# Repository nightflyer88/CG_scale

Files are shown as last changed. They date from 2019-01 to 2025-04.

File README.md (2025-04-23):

# CG scale

The CG Scale firmware is open source and available for free. If you like it, support the project with a donation and help it continue to develop.

Donate (https://www.paypal.com/cgi-bin/webscr?cmd=_s-xclick&hosted_button_id=R69PMKTCXQBUU&source=url)

Arduino-based balance scale for weighing model aircraft. Relatively few components are required and should be easy to recreate even for electronics beginners.
The most important functions:

- supports scales with 2 or 3 load cells
- supports ESP8266 (also Wifi Kit 8) and Arduino with ATmega328, ATmega32u4
- Automatic calibration based on a reference object, meaning no laborious determination of the calibration values
- Display via OLED display
- Battery voltage can be measured
- Settings are made through a menu via the serial interface
- With the ESP8266, the settings can also be easily made via the webpage
- Parameters are permanently saved in the EEprom and do not have to be re-parameterized after a software update
- Only a few components required, making it quick and easy to assemble

# ENGLISH

Here is the assembly and user guide for this scale model balance
You can find the full description [HERE](https://github.com/ZINKTiti/CG_scale-1/wiki/ENGLISH)

# FRANCAIS

Voici le guide de montage et d'utilisation de cette balance pour model réduit
Vous trouver toute la description [ICI](https://github.com/ZINKTiti/CG_scale-1/wiki/FRANCAIS)

# DEUTSCH

Hier finden Sie die Montage- und Bedienungsanleitung für diese Modellwaage
Sie finden die gesamte Beschreibung [HIER](https://github.com/nightflyer88/CG_scale/wiki)

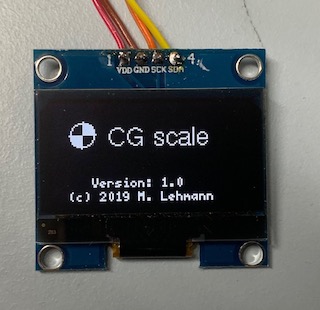
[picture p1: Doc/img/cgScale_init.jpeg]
init

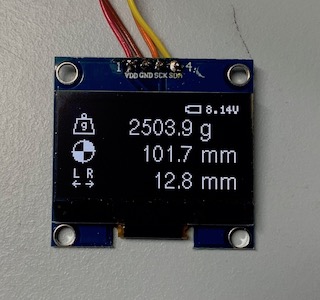
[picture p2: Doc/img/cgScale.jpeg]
run

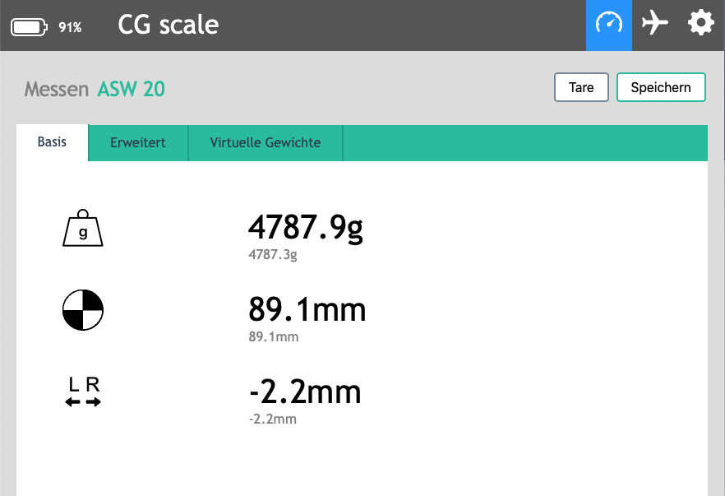
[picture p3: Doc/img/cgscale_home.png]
cgscale_home

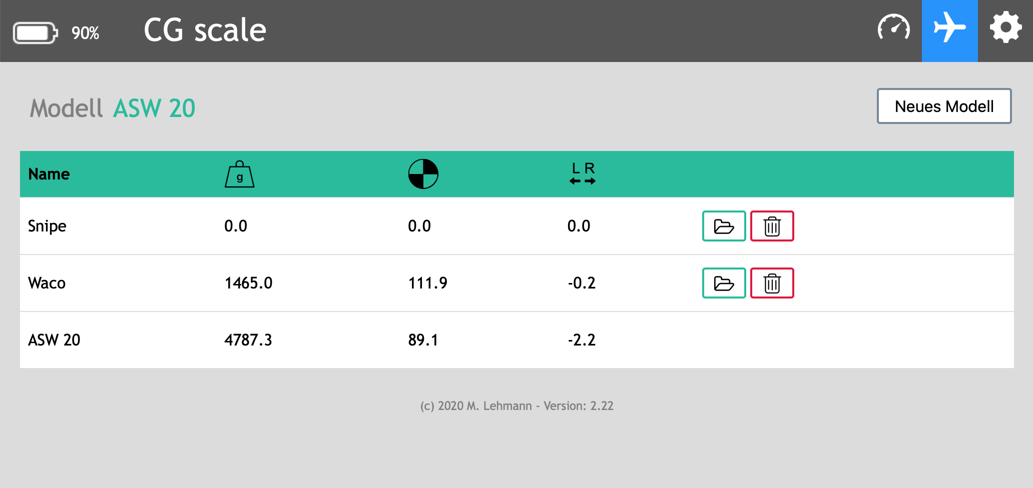
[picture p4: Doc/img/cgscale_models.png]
cgscale_models

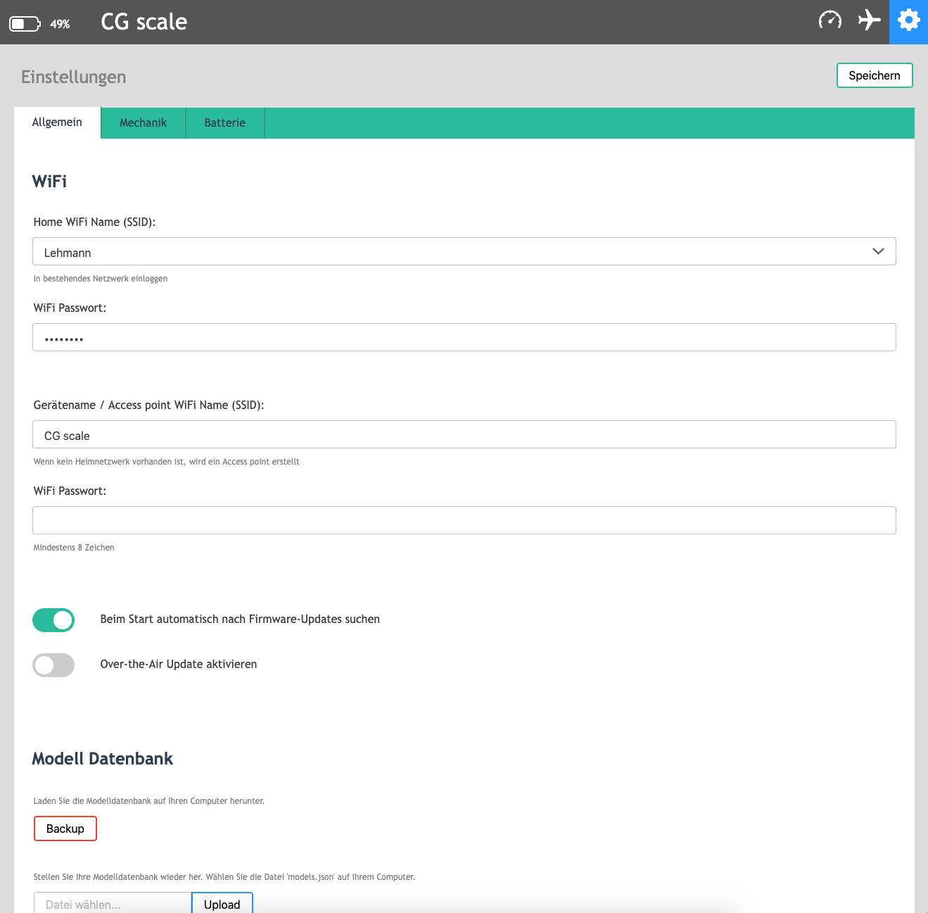
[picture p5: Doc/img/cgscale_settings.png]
cgscale_settings

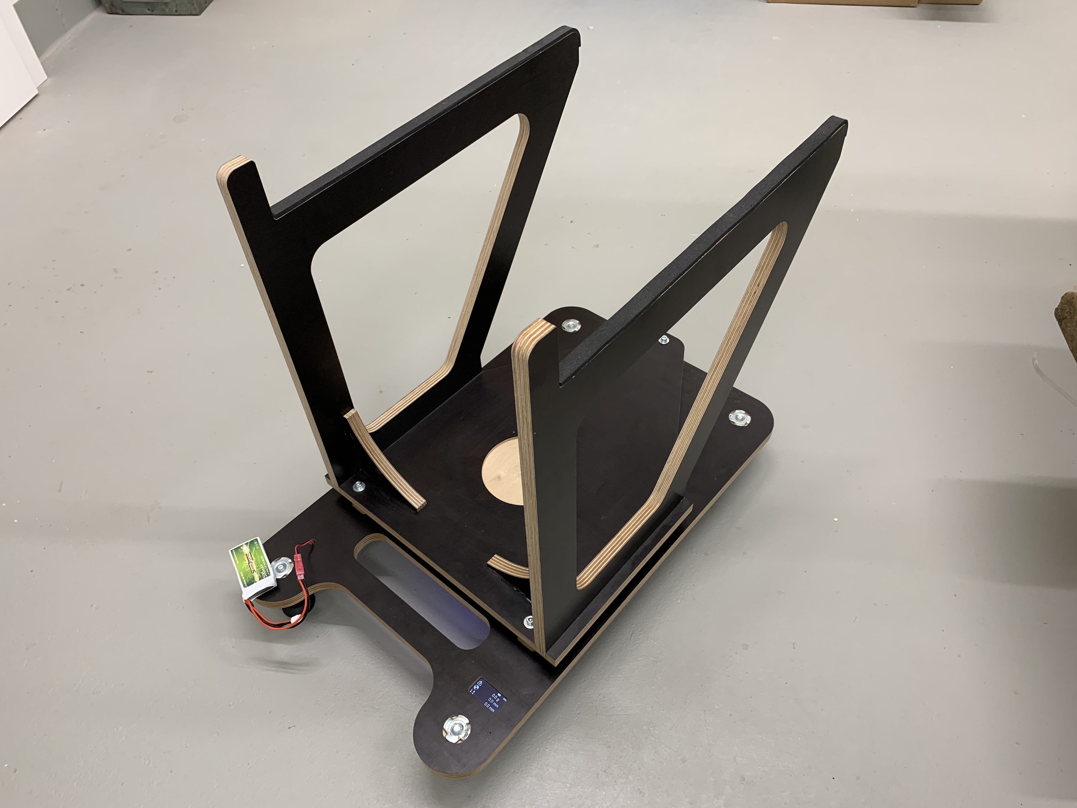
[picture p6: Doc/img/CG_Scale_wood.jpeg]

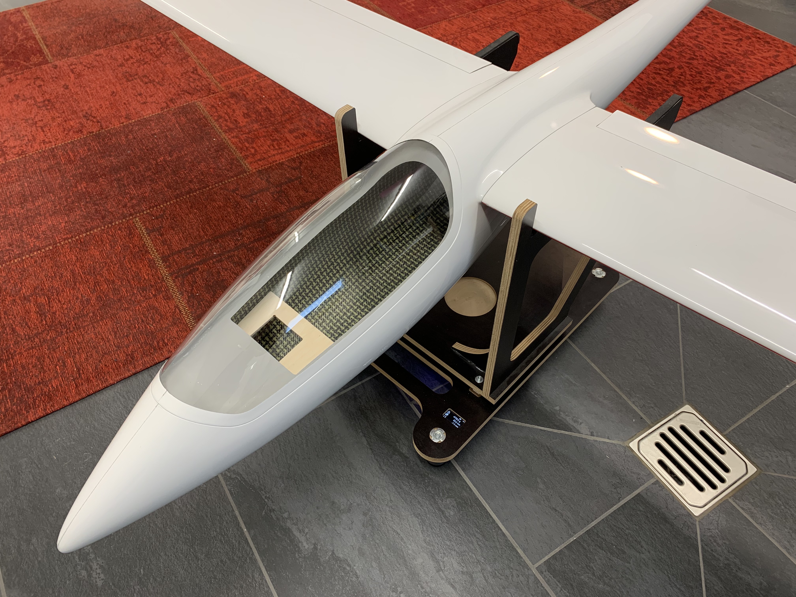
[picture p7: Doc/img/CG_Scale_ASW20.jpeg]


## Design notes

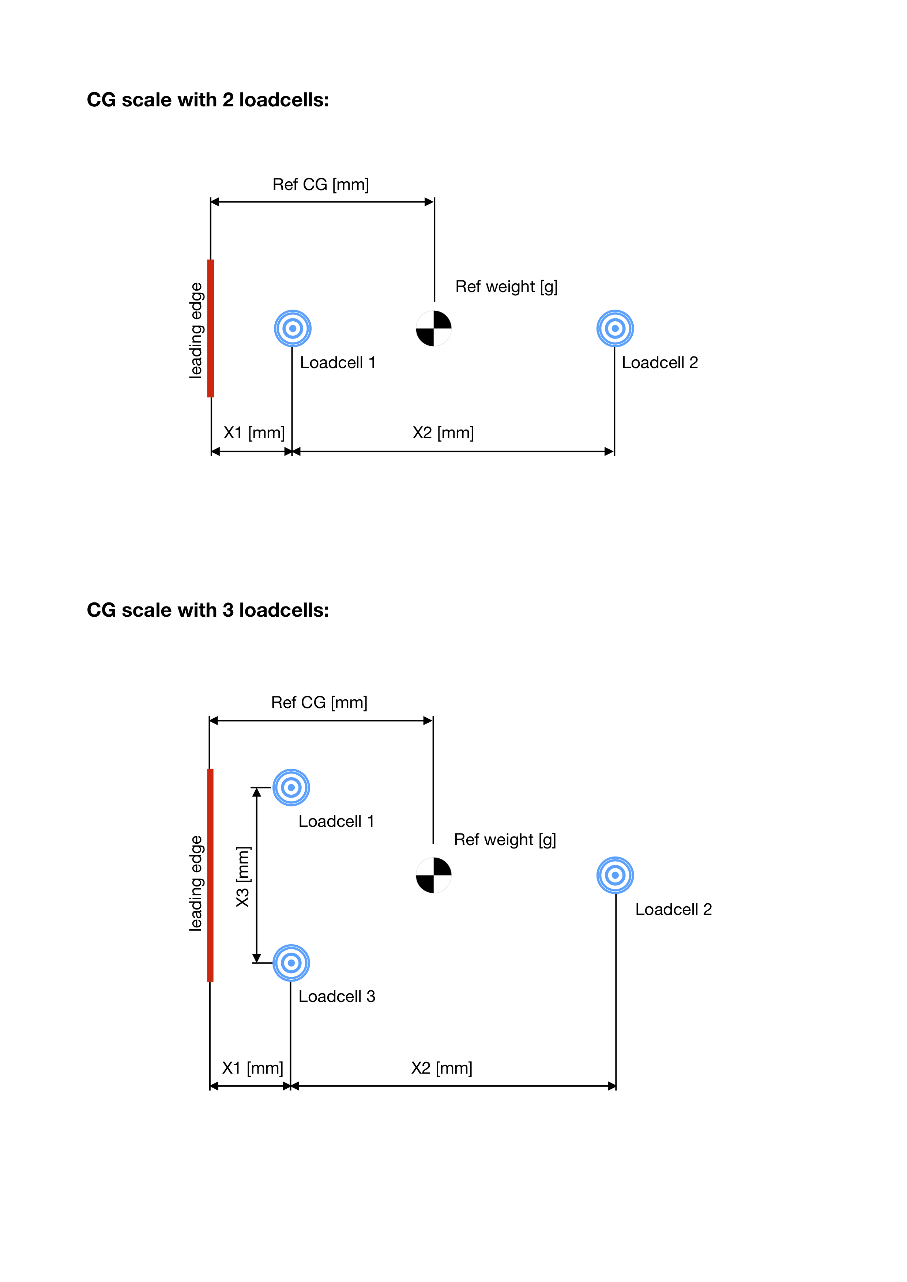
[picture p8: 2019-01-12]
Doc/CG_scale_mechanics.png

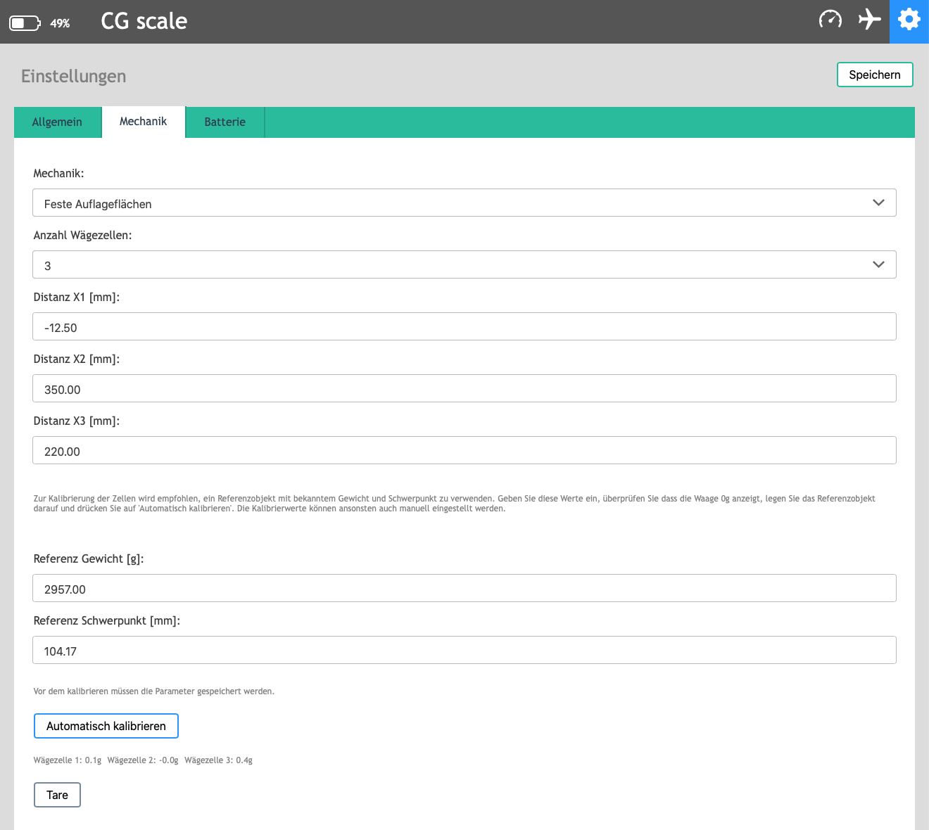
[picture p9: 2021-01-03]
Doc/img_DE/cgscale_settings_mechanic.png

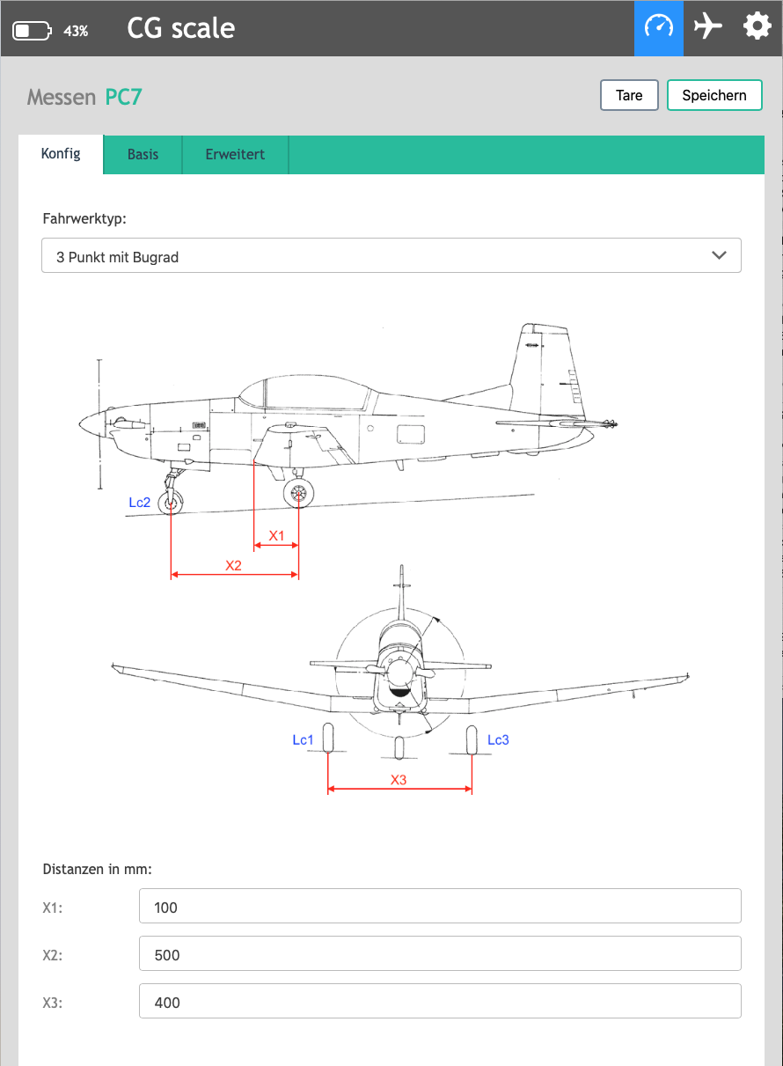
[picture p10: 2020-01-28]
Doc/img_DE/cgscale_V2_homeconfig3.png

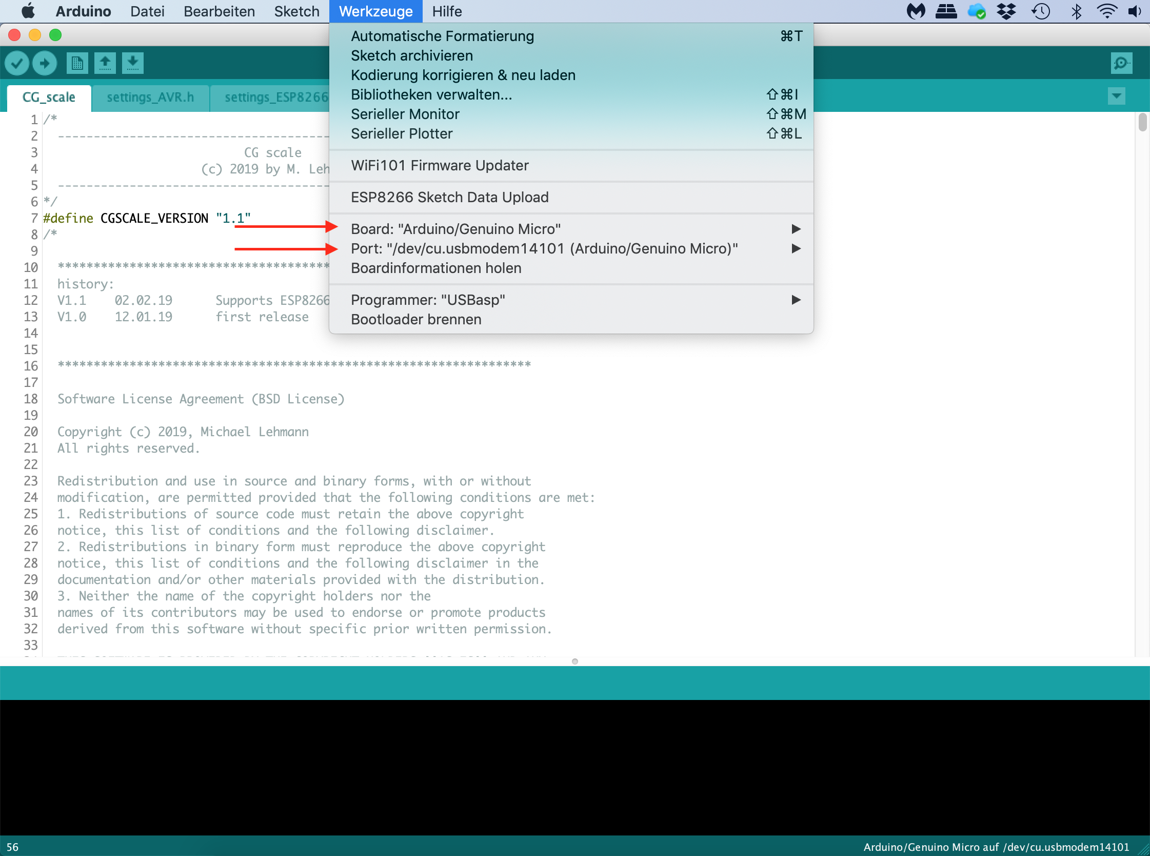
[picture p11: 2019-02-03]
Doc/img_DE/arduino_board.png

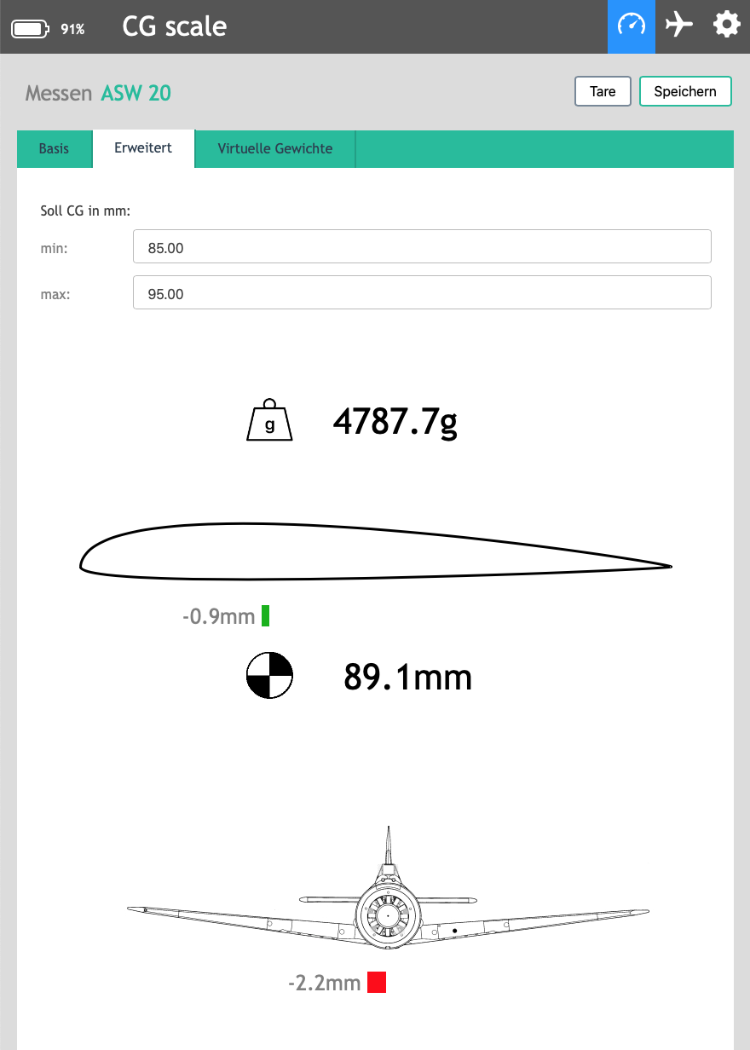
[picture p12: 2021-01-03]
Doc/img_DE/cgscale_home_extended.png

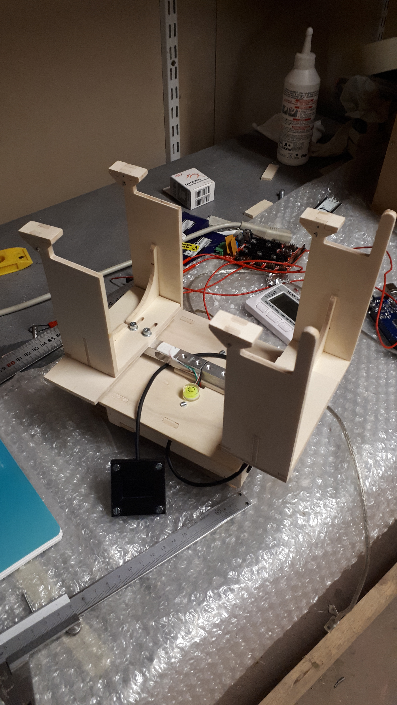
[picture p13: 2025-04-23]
Doc/Oled BOX/img/Balance.jpg

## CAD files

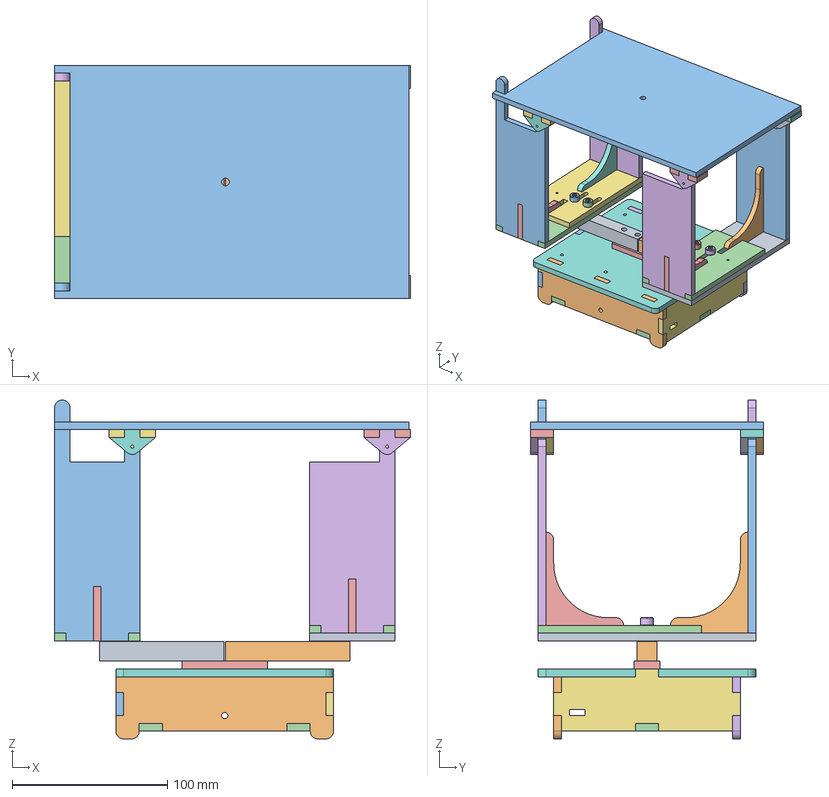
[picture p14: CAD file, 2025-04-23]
Doc/Balance CPT 5mm/Freecad/Balance 5mm.FCStd
229.0 x 150.0 x 218.0 mm
Dessus ESP8266
Coté droit
Avant
Dessous
Calle
CoterGauche
Arriere
Dessus ArduinoNano
Load Cell
M5x20-Screw
M5x20-Screw004
M5x20-Screw005
M5x20-Screw006
M5x20-Screw007
M5x20-Screw008
M5x20-Screw009
M5x20-Screw010
SupportLateralAvantGauche
PlateauBasGauche
RaidisseurGauche
SupportLateralAvantDroit
PlateauBasDroit
RaidisseurDroit
PlateauBasArriereDroit
RaidisseurGaucheDroit
SupportLateralArriereDroit
PlateauBasDroitArriere
RaidisseurDroitArriere
SupportLateralArriereGauche
SupportReposeAile
SupportLateral
SupportLateral001

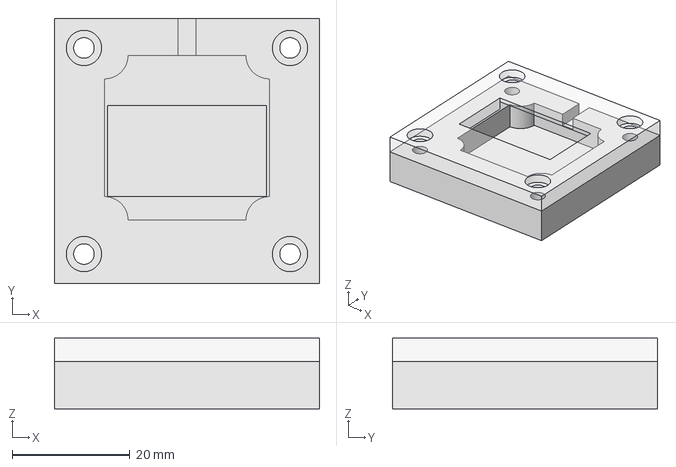
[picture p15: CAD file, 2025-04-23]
Doc/Oled BOX/FreeCad Files/Box_Oled.FCStd
45.0 x 45.0 x 12.0 mm
Couvercle001
Bas001

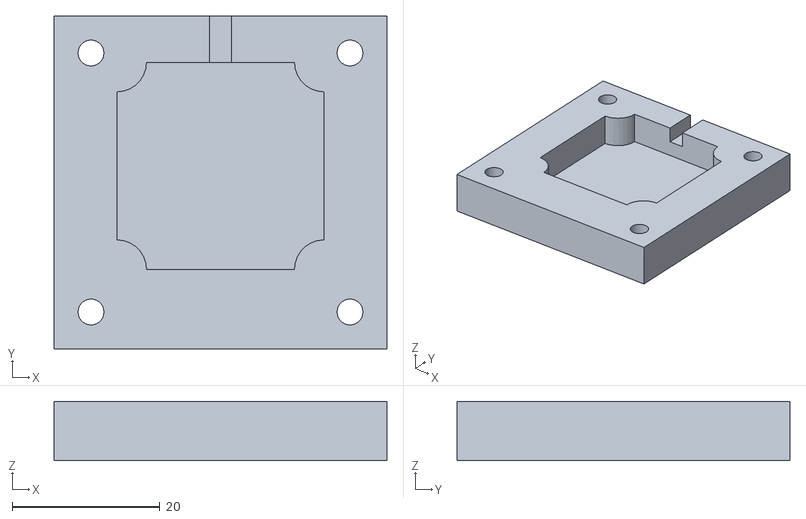
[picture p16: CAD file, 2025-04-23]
Doc/Oled BOX/Stl/Box_Oled_Bottom.stl
45.0 x 45.0 x 8.00

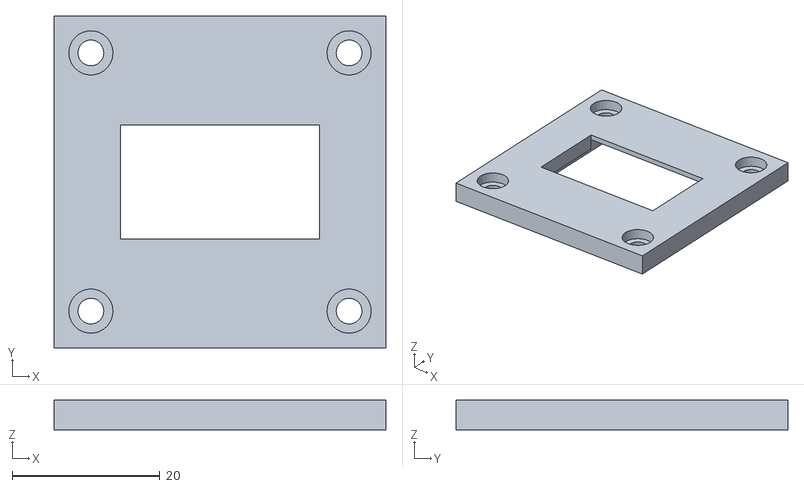
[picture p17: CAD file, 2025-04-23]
Doc/Oled BOX/Stl/Box_Oled_Top.stl
45.0 x 45.0 x 4.00

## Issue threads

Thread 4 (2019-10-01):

NodeMCU mit CG Scale Verbindungsprobleme mit lokalem Wifi

kkberg, 2019-10-01:
Leider verbindet sich das System nicht mit dem lokalen WiFi, obwohl SSID und Wlan-Schlüssel korrekt sind. Parameter werden gespeichert und das wird auch bestätigt.
Nach dem Speichern bleibt  CG Scale als SSID, also im AP-Modus, was auch nach Neustart so bleibt.

kkberg, 2019-10-01:
Es sieht m.E. so aus, dass nicht lange genug nach vorhandenen WiFi's gesucht wird und dadurch direkt in den AP-Modus gewechselt wird.

kkberg, 2019-10-01:
Ich denke das es diese Stelle ist, die ich verändern muss.
#define TIMEOUT_CONNECT 25000   //ms

nightflyer88, 2019-10-07:
Was hast du denn für einen Router ? Es ist möglich das einige etwas mehr Zeit benötigen. Mit 25000ms funktioniert es ?

kkberg, 2019-10-07:
Ich habe eine Fritzbox 7590. Den Wert habe ich angepasst auf 50000ms und das funktioniert. Ich habe inzwischwn auch eine RS232 to Wifi Bridge gefunden, was für mich noch angenehmer ist. Ost es angedacht so etwas auch noch zu implementieren? Übrigens eine tolle Arbeit die Du gemacht hast. TOP

nightflyer88, 2019-10-07:
Bis jetzt ist sowas nicht angedacht. Für was brauchst du die Bridge, oder wie funktioniert das genau ?

kkberg, 2019-10-07:
Ich brauche nur eine Com-Port, ohne eine Oberfläche.

kkberg, 2019-10-07:
Entschuldige bitte, ich habe das jetzt falsch gepostet. Das sollte hier nicht rein. Ich habe noch ein Projekt mit ESP und mir ist was durcheinander geraten.

Closed 2019-10-07.

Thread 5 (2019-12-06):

Drehmoment des Flügelpaares beim messen des Rumpfes addieren

Rolf-G, 2019-12-06:
Erst mal vielen Dank für das hervoragende und sehr praxistaugliche Programm. Die Möglichkeit, mehrere Modelle (mit jeweils eigenen Abständen der Wägepunkte/Referenzpunkt) ist genial. Leider reichen meine Programmier Kenntnisse nicht aus, um selbst folgende Erweiterung einzupflegen, daher schlage ich das einfach mal hier vor:

Könnte zur tatsächlichen Messung bedarfsweise ein weiteres "virtuelles" Drehmoment (Gewicht/Abstand) mit gerechnet werden ?

Nimmt man die abmontierten Flügel und bestimmt deren Schwerpunkt/Gewicht einmal alleine, und nimmt diese Werte dann als "virtuelles" Gewicht, könnte man beim Bauen am Rumpf in der Werkstatt (wo man im allgemeinen ja besonderes bei drößeren Fliegern die Flügel eben nicht montiert hat) allein durch Auswiegen des Rumpfes ablesen, wo später bei montiertem Flächeln der Schwerpunkt sein wird. Man bräuchte zum Überprüfen also nicht jedesmal die Flügel montieren.

Hoffe, ich habe mich halbwegs verständlich ausgedrückt.
MfG Rolf

nightflyer88, 2020-11-01:
Eingebaut bei V2.2

Rolf-G, 2020-11-02:
Suuuuuuuuuuper, tausend Dank

Closed 2020-11-01.

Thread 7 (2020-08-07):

Fehler der Version 2.0 beim Kompilieren.

Skippydi, 2020-08-07:
Beim Kompilieren der V2.0 erscheint folgender Fehler:

Sketch wird kompiliert...

CG_scale:103:13: error: 'MAX_MODELNAME_LENGHT' was not declared in this scope

   char name[MAX_MODELNAME_LENGHT + 1] = "";

             ^~~~~~~~~~~~~~~~~~~~

Bibliothek HX711_ADC in Version 1.2.1 im Ordner: C:\Users\Skippy\Documents\Arduino\libraries\HX711_ADC  wird verwendet

Bibliothek U8g2 in Version 2.27.6 im Ordner: C:\Users\Skippy\Documents\Arduino\libraries\U8g2  wird verwendet

Bibliothek EEPROM in Version 2.0 im Ordner: C:\Program Files (x86)\Arduino\hardware\arduino\avr\libraries\EEPROM  wird verwendet

Bibliothek Wire in Version 1.0 im Ordner: C:\Program Files (x86)\Arduino\hardware\arduino\avr\libraries\Wire  wird verwendet

Bibliothek SPI in Version 1.0 im Ordner: C:\Program Files (x86)\Arduino\hardware\arduino\avr\libraries\SPI  wird verwendet

exit status 1

'MAX_MODELNAME_LENGHT' was not declared in this scope

Mein Fehler oder, fehlt das was??

Gruß Dietmar

Skippydi, 2020-08-08:
Hat sich erledigt

fheinze26, 2020-09-24:
Hi @Skippydi und @nightflyer88
ich versuche gerade die Version 2.0 auf einen Arduino UNO zu installiere und bekomme eine ganz ähnlich Fehlermeldung. Wie habt ihr das Problem gelöst? VIELEN DANK

Arduino: 1.8.12 (Mac OS X), Board: "Arduino Uno"

In file included from /Users/fheinze/Downloads/CG_scale/CG_scale.ino:83:0:
settings_AVR.h:54:39: error: 'A9' was not declared in this scope
 #define PIN_LOADCELL3_DOUT            A9
                                       ^
/Users/fheinze/Downloads/CG_scale/CG_scale.ino:89:136: note: in expansion of macro 'PIN_LOADCELL3_DOUT'
 HX711_ADC LoadCell[]{HX711_ADC(PIN_LOADCELL1_DOUT, PIN_LOADCELL1_PD_SCK),HX711_ADC(PIN_LOADCELL2_DOUT, PIN_LOADCELL2_PD_SCK),HX711_ADC(PIN_LOADCELL3_DOUT, PIN_LOADCELL3_PD_SCK)};
                                                                                                                                        ^~~~~~~~~~~~~~~~~~
sketch/settings_AVR.h:54:39: note: suggested alternative: 'A7'
 #define PIN_LOADCELL3_DOUT            A9
                                       ^
/Users/fheinze/Downloads/CG_scale/CG_scale.ino:89:136: note: in expansion of macro 'PIN_LOADCELL3_DOUT'
 HX711_ADC LoadCell[]{HX711_ADC(PIN_LOADCELL1_DOUT, PIN_LOADCELL1_PD_SCK),HX711_ADC(PIN_LOADCELL2_DOUT, PIN_LOADCELL2_PD_SCK),HX711_ADC(PIN_LOADCELL3_DOUT, PIN_LOADCELL3_PD_SCK)};
                                                                                                                                        ^~~~~~~~~~~~~~~~~~
settings_AVR.h:55:39: error: 'A10' was not declared in this scope
 #define PIN_LOADCELL3_PD_SCK          A10
                                       ^
/Users/fheinze/Downloads/CG_scale/CG_scale.ino:89:156: note: in expansion of macro 'PIN_LOADCELL3_PD_SCK'
 HX711_ADC LoadCell[]{HX711_ADC(PIN_LOADCELL1_DOUT, PIN_LOADCELL1_PD_SCK),HX711_ADC(PIN_LOADCELL2_DOUT, PIN_LOADCELL2_PD_SCK),HX711_ADC(PIN_LOADCELL3_DOUT, PIN_LOADCELL3_PD_SCK)};
                                                                                                                                                            ^~~~~~~~~~~~~~~~~~~~
sketch/settings_AVR.h:55:39: note: suggested alternative: 'A1'
 #define PIN_LOADCELL3_PD_SCK          A10
                                       ^
/Users/fheinze/Downloads/CG_scale/CG_scale.ino:89:156: note: in expansion of macro 'PIN_LOADCELL3_PD_SCK'
 HX711_ADC LoadCell[]{HX711_ADC(PIN_LOADCELL1_DOUT, PIN_LOADCELL1_PD_SCK),HX711_ADC(PIN_LOADCELL2_DOUT, PIN_LOADCELL2_PD_SCK),HX711_ADC(PIN_LOADCELL3_DOUT, PIN_LOADCELL3_PD_SCK)};
                                                                                                                                                            ^~~~~~~~~~~~~~~~~~~~
CG_scale:103:13: error: 'MAX_MODELNAME_LENGHT' was not declared in this scope
   char name[MAX_MODELNAME_LENGHT + 1] = "";
             ^~~~~~~~~~~~~~~~~~~~
exit status 1
'A9' was not declared in this scope

Dieser Bericht wäre detaillierter, wenn die Option
"Ausführliche Ausgabe während der Kompilierung"
in Datei -> Voreinstellungen aktiviert wäre.

Skippydi, 2020-09-24:
Das Problem ist, das die Firmware für einen ESP8266 geschrieben wurde. Mit einem ESP hatte ich den Fehler nicht mehr. Außerdem ist der auch erheblich komfortabler mit WLAN.

fheinze26, 2020-09-24:
Danke für die schnelle Antwort @Skippydi
Ich habe jetzt alle Versionen bis 1.0 durchprobiert und immer erhalten ich denselben Fehler "A9' was not declared in this scope" - Es scheint im allgemeinen nicht mit dem ATmega328 zu funktionieren oder ich mach was falsch. Dann probiere ich mal einen ESP8266. Ist nur schade weil ich noch ein paar Arduino UNOs zuhause rumliegen habe. Danke nochmal

Skippydi, 2020-09-24:
Der UNO hat keinen A9 Input/Output das ist das Problem

Von meinem iPhone gesendet

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

fheinze26, 2020-09-24:
Stimmt, der hat ja nur Analog A0-A5 jetzt wo Du´s sagst, macht total Sinn ;)

Closed 2020-08-08.

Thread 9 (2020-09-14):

Tara Button auf Kalibrierungs-Seite

Blackforrestpilot, 2020-09-14:
Verbesserungsvorschlag:
Einen Tara Button auf der Kalibrierungs Seite einfügen.
Das Kalibrieren wird dann vereinfacht und weniger fehlerfällig.
Ich würde das gerne selber programmieren,finde aber die Sourcen der Web GUI nicht.

Gruss
Christoph

nightflyer88, 2020-09-27:
Habe ich nun eingebaut, ist aber noch nicht getestet: d1ad6b6c4293ef6ffc48abfb7cc4e12905cb4f5f

Closed 2020-09-27.

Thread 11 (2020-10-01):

Seltsame Gewichtsanzeige bzw. falsches Gewicht ESP8266

Skippydi, 2020-10-01:
Erstmal vielen Dank für die Software. Ich habe sie auf einem EP8266 installiert mit 2 Wägezellen (Rot von Aliexpress 5kg). Soweit funktioniert auch alles, aber das angezeigt Gewicht stimmt hinten und vorne nicht. Beim Kalibrieren habe ich ein Gewicht von 1711g SP 112.5mm eingesetzt, angezeigt wird nach dem kalibrieren 1712.9 und SP 113.4. Damit könnte ich leben. Aber beim normalen wiegen zeigt die Waage zwischen 1917g und 1735g an. Bei verschieden Wiegevorgängne habe ich niemals ein gleiches Gewicht, schon gar nicht das Kalibriergewicht. Woran könnte das liegen?
Danke für eine Antwort.

nightflyer88, 2020-10-03:
Evtl. falsch verdrahtet oder Wiegezelle/HX711 defekt. Ist die Betriebsspannung der HX711 auf 3.3v stabilisiert ?

Skippydi, 2020-10-03:
Die HX711 sind richtig verdrahtet,(mit separater Software getestet und auch nachkontrolliert),
 die 3.3 Volt liefert der ESP8266, sollte also auch ok sein. Seltsam ist nur das beim Kalibrieren das richtige Gewicht +/- 2 Gramm richtig berechnet wird.
Wenn ich jedoch meinen Segler wiege, der 460g wiegt, wird 682g angezeigt. Aber der berechnete SP stimmt fast zu 100% ( 54.2mm statt 55mm)
Ich bin echt ratlos.

nightflyer88, 2020-10-04:
In den Einstellungen siehst du die Einzelgewichte der Zellen, belaste jede Zelle separat mit einem Gewicht, und prüfe was dabei angezeigt wird. Es könnte sein, dass eine Zelle defekt ist. Hast du die Abstände richtig eingegeben ? Was für Kalibrierwerte hast du ?

Skippydi, 2020-10-04:
Hallo Nightflyer88, es tatsächlich eine Alumesszelle defekt. Habe ich ausgetauscht und jetzt sind die Messwerte und die Kalibrierung TOP!! Ganz herzlichen Dank für deine HIlfe. Die Messzelle funktionierte zwar, aber stellte sich nicht immer korrekt auf Null.

Closed 2020-10-04.

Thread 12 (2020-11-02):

V2.2 Zu wenig Speicherplatz

chaoscrack, 2020-11-02:
Das hochladen der neuen Firmware ging gut. Jedoch beim upload des Filesystems erhielt ich die Fehlermeldung dass nicht genügend Speicherplatz vorhanden sei.
Um auszuschliessen dass der Speicher beim Update gelöscht wurde hab ich nochmals alles via pyFlascher hochgeladen und vorher den Speicher löschen lassen. Leider blieb das Problem das selbe.
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

Rolf-G, 2020-11-04:
Hallo Patrick, ich hatte nach dem Laden der Firmware mit dem NodeMCU pyFlasher erst das Problem, das die update Seite nicht gefunden wurde (vermute, weil eine 1.x Version vorher drauf war) und die Webseiten noch die alten waren. Habe mir dann geholfen, indem ich das Filesystem einfach mit dem ESP8266 Sketch upload Tool im Arduino INO Programm hochgeladen habe.

chaoscrack, 2020-11-05:
@Rolf-G
Wie geschrieben hab ich mit dem flashen zuerst alles löschen lassen. Ohne Erfolg.
Update-Seite kann ich aufrufen. Nur anschliessend krieg ich die erwähnte Fehlermeldung.

Mittels Arduino IDE kann ich das Filesystem hochladen, doch ich verliere ich anschliessend immer wieder die Verbindung zum AccessPoint und kann somit auch nicht die Haupt- oder Setupseite aufrufen.

Wenn ich versuche den ESP via Arduino IDE zu flashen erhalte ich schon beim Kompilieren Fehlermeldungen. Diese lautet ` 'class HTTPClient' has no member named 'setRedirectLimit'` und die IDE steht bei der Zeile 1128 https.setRedirectLimit(0);

chaoscrack, 2020-11-08:
Ich habs auch mit einem Wemos D1 mini V3.1.0 probiert. Die Fehlermeldungen sind die selben.
@nightflyer88 mach ich was falsch, oder wo könnte der Fehler liegen?

nightflyer88, 2020-11-27:
ist mit V2.21 behoben

Closed 2020-11-27.

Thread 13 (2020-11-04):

virtuelle Gewichte pro Modell

jraichle, 2020-11-04:
Hi Michael,
denke es wäre sinnvoll wenn die virtuellen Gewichte je Modell gespeichert würden. Also Akku als virtuelles Gewicht sollte beim Modell A anders sein als beim Modell B.
Noch eine Idee: wäre es möglich dass auf der Haupseite immer das aktuelle gewogene Gewicht und SP angezeigt wird, unabhängig ob virtuelle Gewichte aktiv sind oder nicht? Das neue virtuelle Gewicht dann nur auf der virtuellen Gewichtsseite anzeigen (auf der auch die virtuellen Gewichte ein-und ausgeschaltet werden), und zwar immer direkt nach aktivieren / deaktivieren eines virt. Gewichts. Dann würde man sich nicht versehentlich das bereits gespeicherte Komplettmodell mit virtuellen Gewichten überschreiben.

Viele Grüße
Jochen

nightflyer88, 2020-11-04:
Die virtuellen Gewichte sollten eigentlich schon pro Modell sein...
Bezüglich Idee, ich werde es anschauen.

Closed 2025-04-23.

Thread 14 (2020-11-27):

V2.2 crashed beim speichern von 3 Modellen

jraichle, 2020-11-27:
Hallo Michael,
wenn ich auf einen Wemos D1 mini die V2.2 installiere crashed diese sobald ich 3 x hintereinander ein neues Modell speichere. Danach startet auch der Wemos nicht mehr, da hilft dann nur ein komplettes neu flashen.
Mit der V2.0 tritt dieser Fehler nicht auf.

Viele Grüße
Jochen

nightflyer88, 2020-11-27:
kannst du es mit V2.21 versuchen ? Ich hatte bei der V2.2 fälschlicherweise noch alte Librarys in meiner IDE

jraichle, 2020-11-27:
Crashed auch mit der V2.21. Habe sowohl selber kompiliert (Bibliotheken sind upgedatet) als auch Dein Bin-File versucht. Crashed bei beiden, Habe es auf insgesamt 3 verschiedenen Wemos versucht, allerdings alle aus der gleichen Lieferung :-(  Schau jetzt mal ob ich noch einen anderen finde. Kannst Du denn mehrere Modelle mit der V2.21 anlegen?

jraichle, 2020-11-27:
crashed auch auf einem Wemos aus einer anderen Lieferung. Bin echt gespannt ob Du mahr als 3 Modelle anlegen kannst; V2.0 funktioniert auf allen ohne Probleme

nightflyer88, 2020-11-28:
Hab es auf die schnelle auch reproduzieren können, wobei ich 6 modelle anlegen konnte, bevor es gecrashed ist. Ich denke irgend ein Speicher läuft über. Kannst du versuchen in der settings.h die JSONDOC_SIZE zu erhöhen ?

jraichle, 2020-11-28:
habe in der SettingsESP8266.h JSONDOC_SIZE von 20000 auf 30000 erhöht, crashed immer noch. Was wäre hier ein sinnvoller Wert?

nightflyer88, 2020-11-28:
es ist die maximale grösse in byte der models.json datei. Versuch mal mit 100'000. Wie gross ist dein Speicher ? 4Mb?

nightflyer88, 2020-11-28:
Sollte nun behoben sein: 19978a726989877e4be5a2f0c4494a4d5e224435

Kannst du es bei dir auch testen ?

jraichle, 2020-11-28:
Hi Michael,
funktioniert!  Tollen Job gemacht :-)

Dankeschön

Closed 2020-11-28.

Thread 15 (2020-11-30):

Nach Update, kein Zugriff mehr auf Web Oberfläche

fheinze26, 2020-11-30:
Hallo @nightflyer88,
nochmal vielen Dank für die tolle Software und die ausführlichen Beschreibungen hier.
Nach dem letzten Update bekomme ich folgende Fehlermeldung wenn ich mich entweder via DNS Name oder IP versuche zu verbinden:
CGscale Error: 404
 File or URL not Found !
Irgendeine Idee was das sein könnte?
Grüße,
Falko

jraichle, 2020-11-30:
Hallo Falko,
kann es sein dass Du das hier vergessen hast?
Nach dem die CG scale das erste mal gebootet hat, wird ein Hotspot CG scale generiert, mit diesem WiFi verbindet man sich nun mit dem Computer. Danach den Webbrowser öffnen, und die Adresse: cgscale.local/update eintippen. Es öffnet sich eine kleine Update Webpage, dort wählt man bei Filesystem die Datei CG_scale_spiffs.bin und drückt auf Filesystem update. Nach erfolgtem update bootet die CG scale neu, und ist nun betriebsbereit.
Gruß Jochen

fheinze26, 2020-12-01:
Mensch Jochen, vielen Dank das wars. Hätte ich auch selber draufkommen können ;) Danke

Closed 2020-12-03.

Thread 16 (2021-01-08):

Sehr große Datei

Antonio307, 2021-01-08:
Hallo, ich habe versucht, das Programm auf 328p und 32u4 hochzuladen, kann es aber nicht.
Die Arduino-IDE gibt einen zu großen Dateifehler zurück.
"C:\\Users\\A_tronc\\AppData\\Local\\Temp\\arduino_build_742244/CG_scale-2.22.ino.elf"
text section exceeds available space in boardSketch uses 33092 bytes (115%) of program storage space. Maximum is 28672 bytes.

Global variables use 1556 bytes (60%) of dynamic memory, leaving 1004 bytes for local variables. Maximum is 2560 bytes.
Sketch too big; see http://www.arduino.cc/en/Guide/Troubleshooting#size for tips on reducing it.
Error compiling for board SparkFun Pro Micro.

Wissen Sie, was passieren könnte?
Vielen Dank.

lhm74, 2021-01-31:
Hallo habe genau das gleiche Problem.
Wäre schön wenn uns jemand helfen könnte.
Gruß Alexander

nightflyer88, 2023-01-21:
Der AVR Code ist für einen Atmega328 vorgesehen. Der 32u4 hat zwar einen gleich grossen Flash, der Bootloader ist jedoch grösser, deshalb ist der Code für den 32u4 zu gross. Mit der Arduino IDE 2.0.3 wird der AVR Code für den 328 mit 94% kompiliert.

Closed 2023-01-21.

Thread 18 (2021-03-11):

Frage zur Erstellung der html Seiten von CG Scale

Fux2, 2021-03-11:
Hallo Michael,

leider habe ich keine E-Mail Adresse gefunden, daher als Issue:
Mit welcher Software hast Du denn die verschiedenen html-Seiten für CG Scale erstellt?
Ich möchte für ein anderes Projekt ähnliche Seiten erstellen zum Anzeigen diverser Temperaturen.

Nutzt Du die normale Arduino IDE zum Programmieren?

Danke und Grüße
Fux

nightflyer88, 2021-03-15:
Hallo Fux

Die html Seiten sind alle von "Hand" programmiert, ohne Designsoftware. Das ESP läuft stabiler wenn html, css, java und images alle in einer Datei sind. Ich kenne keine Software die das so kann...

Gruss Michael

Closed 2021-03-15.

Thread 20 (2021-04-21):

Tare via physical switch (ESP8266), experiment..

ClausTonnesen, 2021-04-21:
I have added a physical switch to Tare the load cells when using the CG-Scale stand alone.
Simple, apart from the limited amount of GPIO pins on the ESP8266, actually close to none free when using 3 load cells.

Simple, hook up to D8 (GPIO15), but that doesn't work for input.. back to reading the manual :(
After reading a bit, I figured that the RX (GPIO3) could be used as input.
It breaks the USB/Serial functionality, but when up and running and everything available via the Web GUI, I can live with that.

I haven't tested GPIO9/10 as my wire was to short, and no jumper around (and running out of time for today).

Anyway.. got it running like this
In .h
// Enable pull up on Tare input pin
#ifdef PIN_TARE_BUTTON
  pinMode(PIN_TARE_BUTTON, INPUT_PULLUP);
#endif

In setup
// use the RX pin for tare button input, BREAKS the USB/Serial interface, comment out for acces via USB!!
#define PIN_TARE_BUTTON               RX

Thoughts

Closed 2025-04-23.

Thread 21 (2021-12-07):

Bug in CGSCALE_VERSION "2.22"

MAES001, 2021-12-07:
Hallo,
ich bin dabei die Waage nachzubauen und auf ein Problem in der CG_scale.ino gestoßen.

Als IDE benutze ich die Arduinoversion 1.8.16 .

In der originalen CG_scale.ino steht in Zeile 1143: https.setFollowRedirects(true);
Das führt zu einem Compilerfehler (bool kann nicht in followRedirects_t convertiert werden).
Nach längerem suchen durch die Bibliotheken habe ich die Zeile folgendermaßen geändert:
_https.setFollowRedirects(HTTPC_FORCE_FOLLOW_REDIRECTS);_

Nun lässt sich das Projekt ohne Probleme compilieren .

Gruß, MAES001

Closed 2025-04-23.

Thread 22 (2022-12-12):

Settings korrekt?

cszielke, 2022-12-12:
in der Datei "settings_WIFI_KIT_8." (Settings for WIFI KIT 8) ist für Loadcell3 folgendes definiert:

#define PIN_LOADCELL3_DOUT            D0
#define PIN_LOADCELL3_PD_SCK          D0

ist das korrekt?
Ich habe leider kein WIFI KIT 8 hier.

nightflyer88, 2023-01-18:
Das WIFI KIT 8 hat leider zuwenig I/Os deshalb werden nur zwei Loadcells unterstützt, es ist egal was in der 3. Loadcell steht

Closed 2023-01-18.

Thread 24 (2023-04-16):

Compilation error in function 'runAutoCalibrate'

goepel, 2023-04-16:
Hallo,

ich verwende das Arduino IDE V2.0.4 und ein Adafruit Feather HUZZAH ESP8266. Beim kompilieren gibt es eine Fehlermeldung 'Compilation error: no return statement in function returning non-void [-Werror=return-type]' die auf ein fehlendes return statement in der Funktion 'runAutoCalibrate' hinweist.
Kann es sein, dass in Zeile 558 noch ein 'return true;' hinzugefügt werden muss?

// run auto calibration
bool runAutoCalibrate() {
  Serial.print(F("\nAutocalibration is running"));
  for (int i = 0; i <= 20; i++) {
    Serial.print(F("."));
    delay(100);
  }
  // calculate weight
  float toWeightLoadCell[] = {0, 0, 0};
  toWeightLoadCell[LC2] = ((refCG - model.distance[X1]) * refWeight) / model.distance[X2];
  toWeightLoadCell[LC1] = refWeight - toWeightLoadCell[LC2];
  if (nLoadcells == 3) {
    toWeightLoadCell[LC1] = toWeightLoadCell[LC1] / 2;
    toWeightLoadCell[LC3] = toWeightLoadCell[LC1];
  }
  // calculate calibration factors
  for (int i = LC1; i <= LC3; i++) {
    calFactorLoadcell[i] = calFactorLoadcell[i] / (toWeightLoadCell[i] / weightLoadCell[i]);
    saveCalFactor(i);
  }

  // finish
  Serial.println(F("done"));
**return true;**
}

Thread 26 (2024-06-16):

Error: Timeout TARE Lc1 Error: Timeout TARE Lc2

Xydf1973, 2024-06-16:
Hallo. Hab die Waage mit einem ESP8266, 2 5kg wägezellen und 2 Hx711 (grüne Platine) nachgebaut. Mit dem NodeMCU-PyFlasher geflasht und das Update vom Filesystem eingespielt.
Beim Einschalten bekomme ich nach dem Startscreen und dem Screen mit dem Hostnamen die oben genannten Fehler.
Hab die Abstände X1 und X2 gemessen und eingegeben aber die Fehler bestehen weiterhin.

Woran kann das liegen?

Lg Chris

Closed 2024-06-16.

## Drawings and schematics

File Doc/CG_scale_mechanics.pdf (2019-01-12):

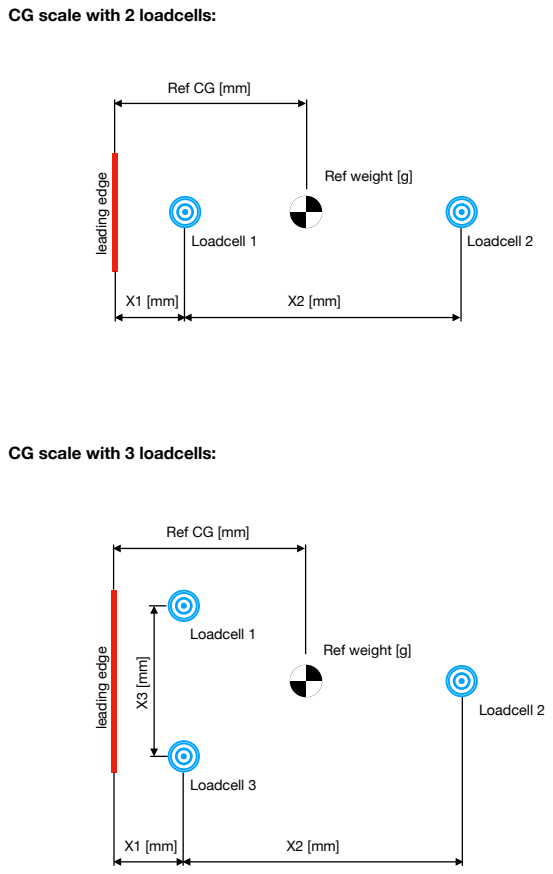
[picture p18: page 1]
Ref weight [g]; Loadcell 1; Loadcell 2; leading edge; Loadcell 3

CG scale with 2 loadcells:

Ref CG [mm]

CG scale with 3 loadcells:

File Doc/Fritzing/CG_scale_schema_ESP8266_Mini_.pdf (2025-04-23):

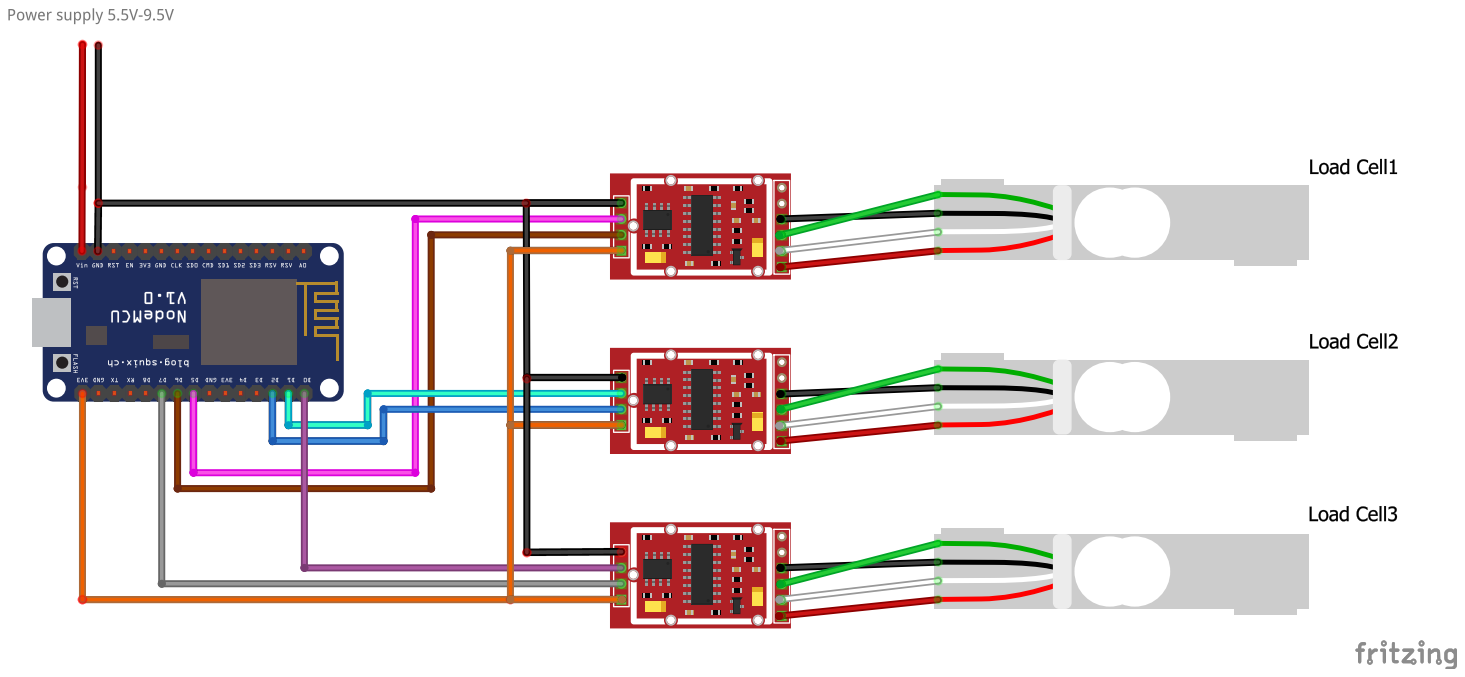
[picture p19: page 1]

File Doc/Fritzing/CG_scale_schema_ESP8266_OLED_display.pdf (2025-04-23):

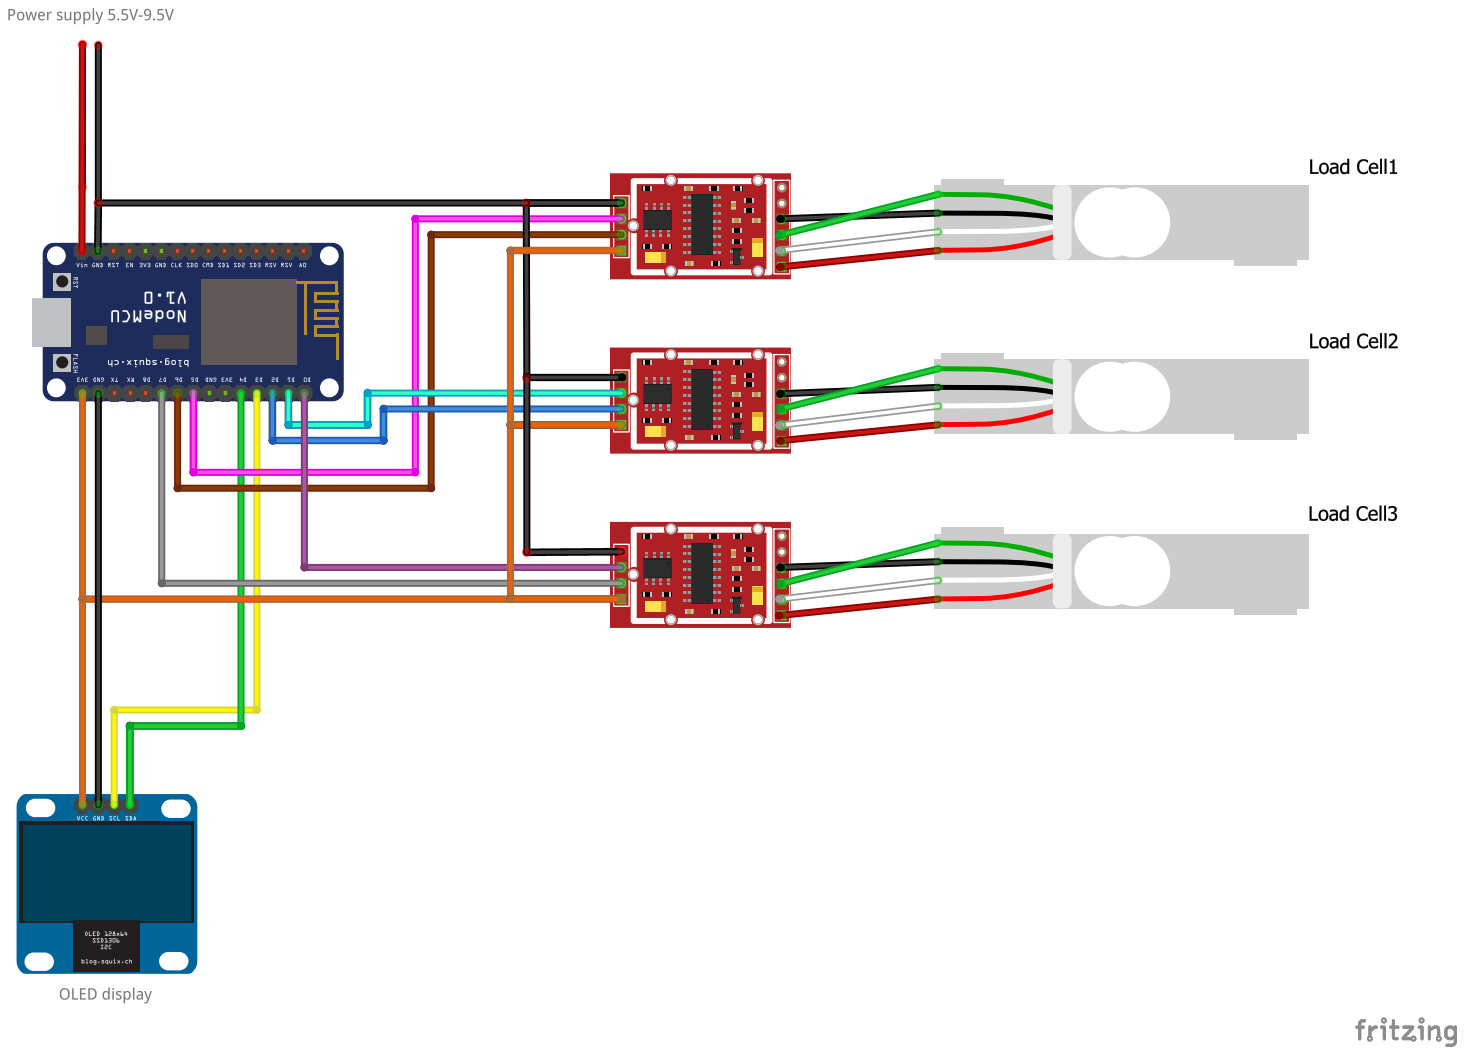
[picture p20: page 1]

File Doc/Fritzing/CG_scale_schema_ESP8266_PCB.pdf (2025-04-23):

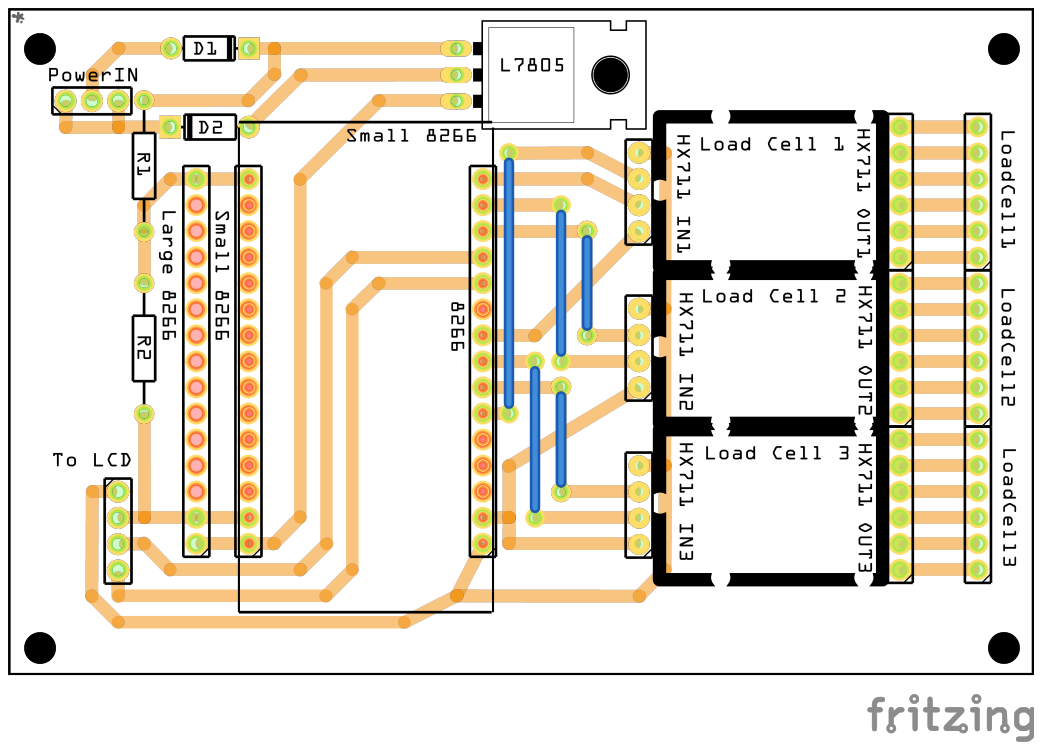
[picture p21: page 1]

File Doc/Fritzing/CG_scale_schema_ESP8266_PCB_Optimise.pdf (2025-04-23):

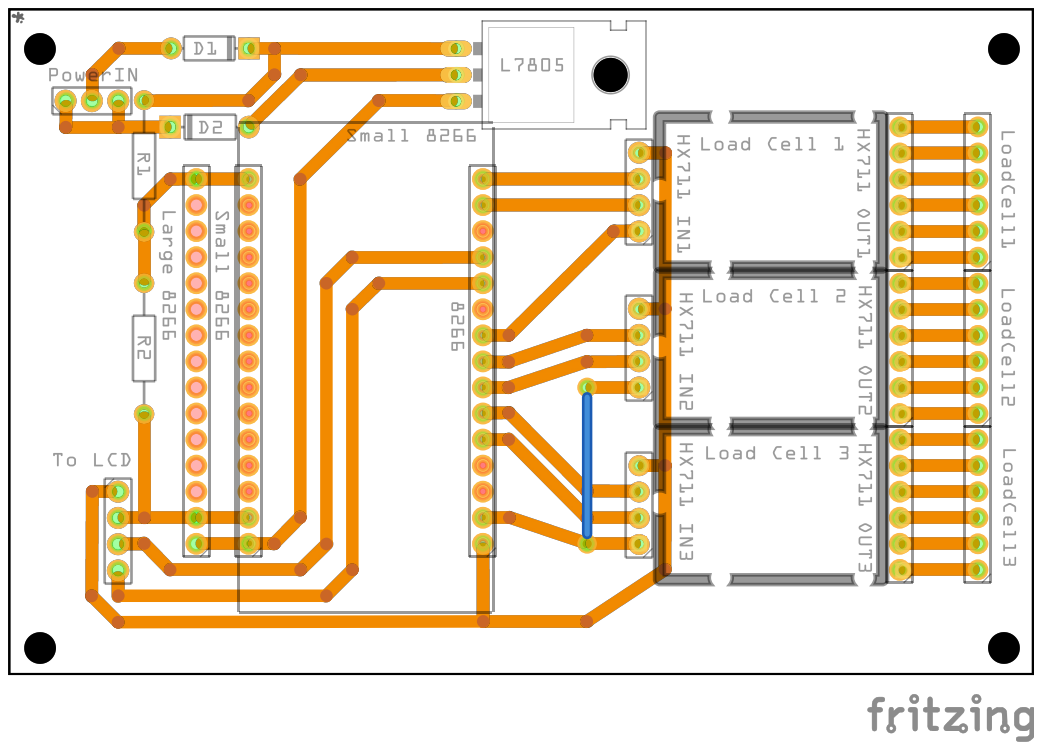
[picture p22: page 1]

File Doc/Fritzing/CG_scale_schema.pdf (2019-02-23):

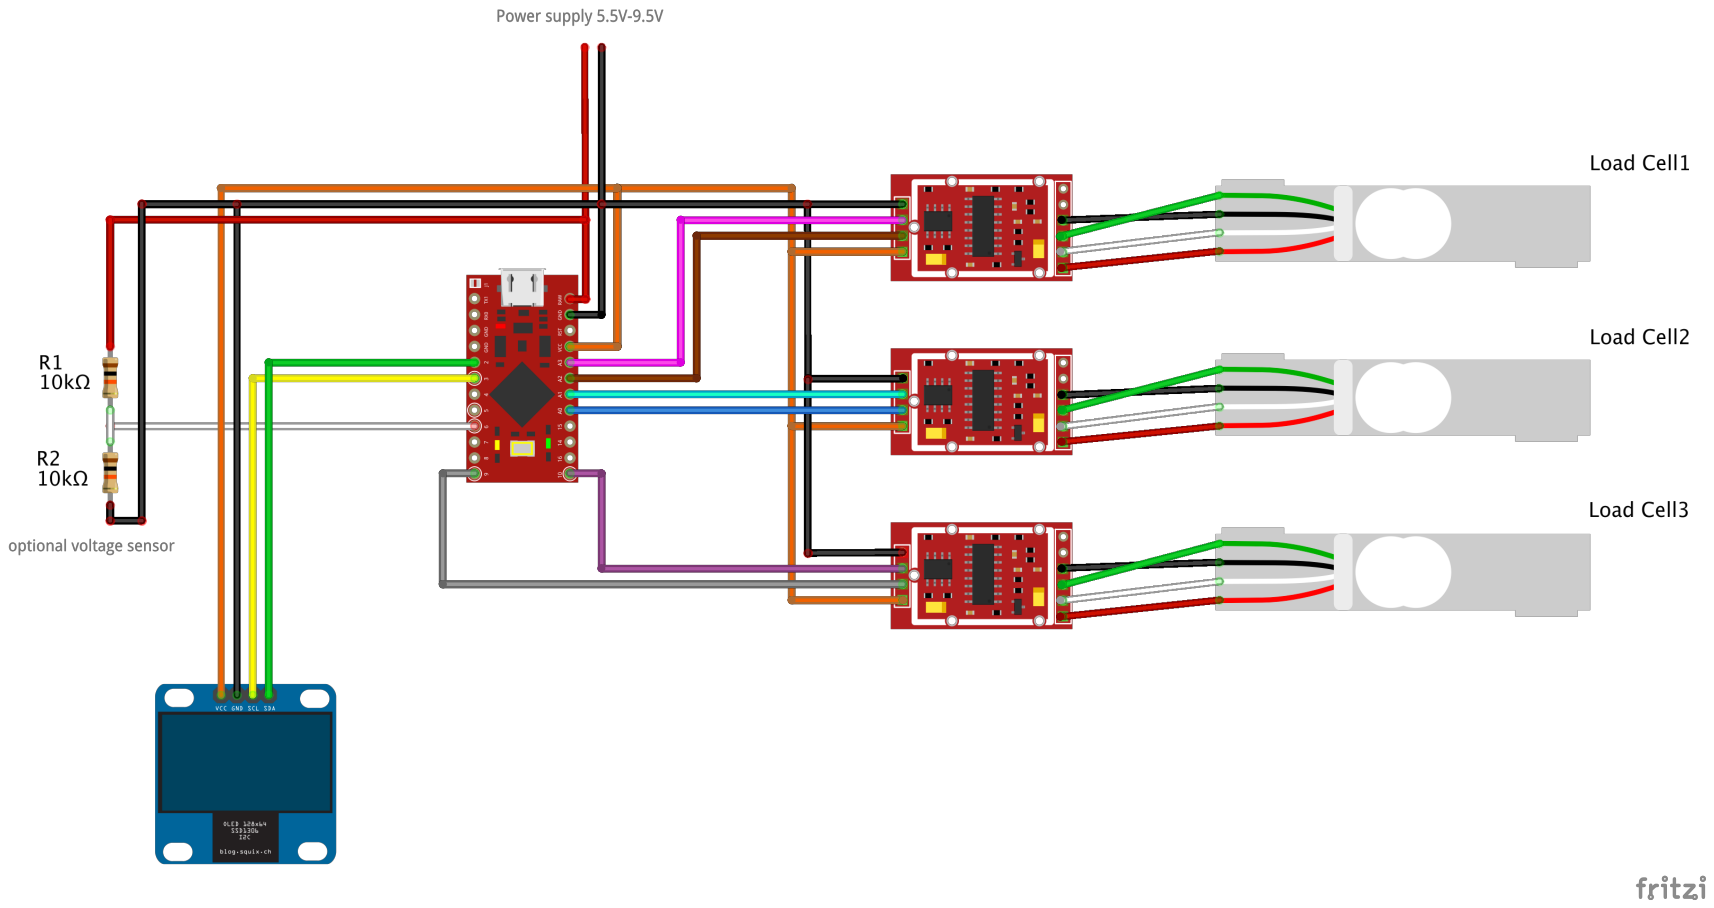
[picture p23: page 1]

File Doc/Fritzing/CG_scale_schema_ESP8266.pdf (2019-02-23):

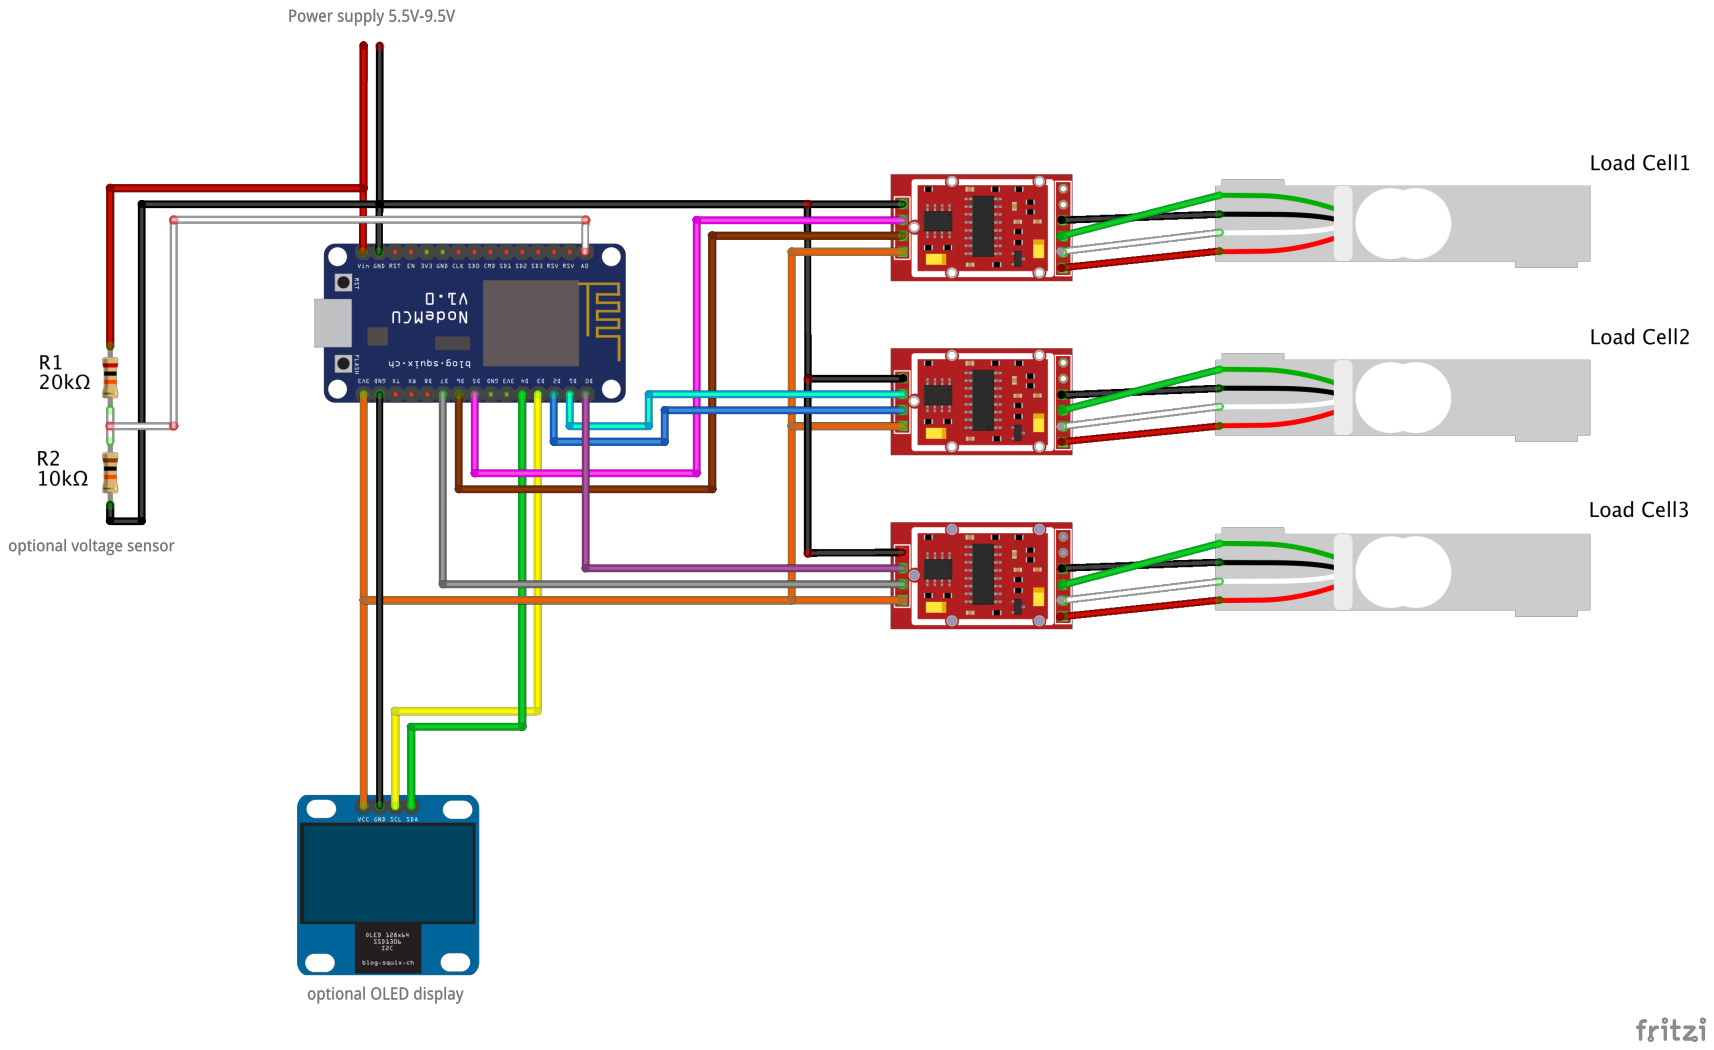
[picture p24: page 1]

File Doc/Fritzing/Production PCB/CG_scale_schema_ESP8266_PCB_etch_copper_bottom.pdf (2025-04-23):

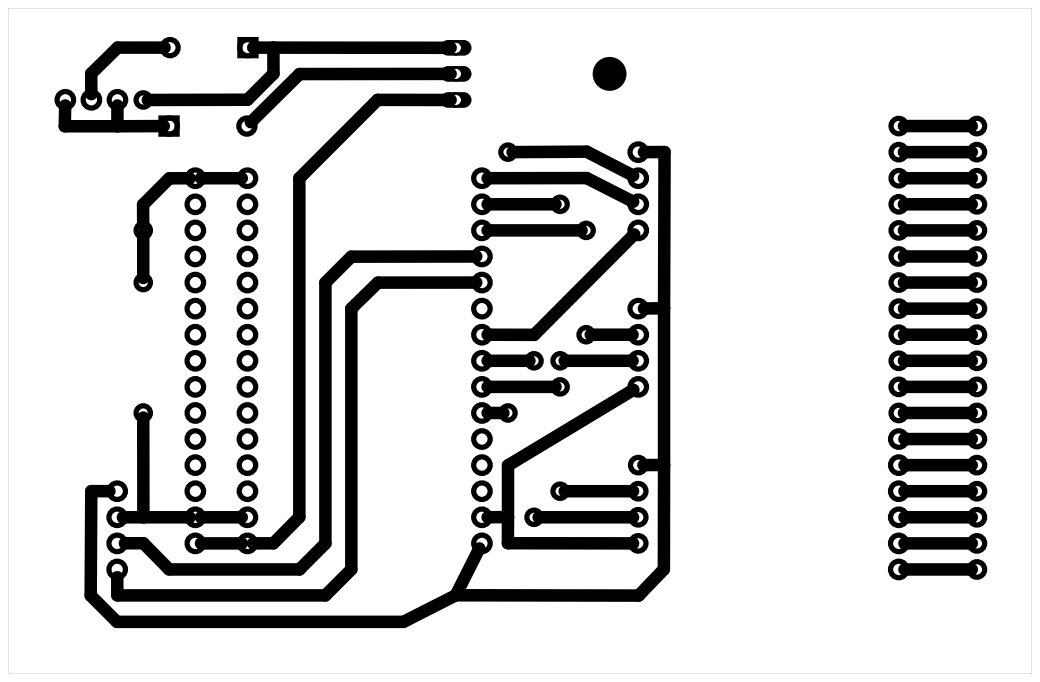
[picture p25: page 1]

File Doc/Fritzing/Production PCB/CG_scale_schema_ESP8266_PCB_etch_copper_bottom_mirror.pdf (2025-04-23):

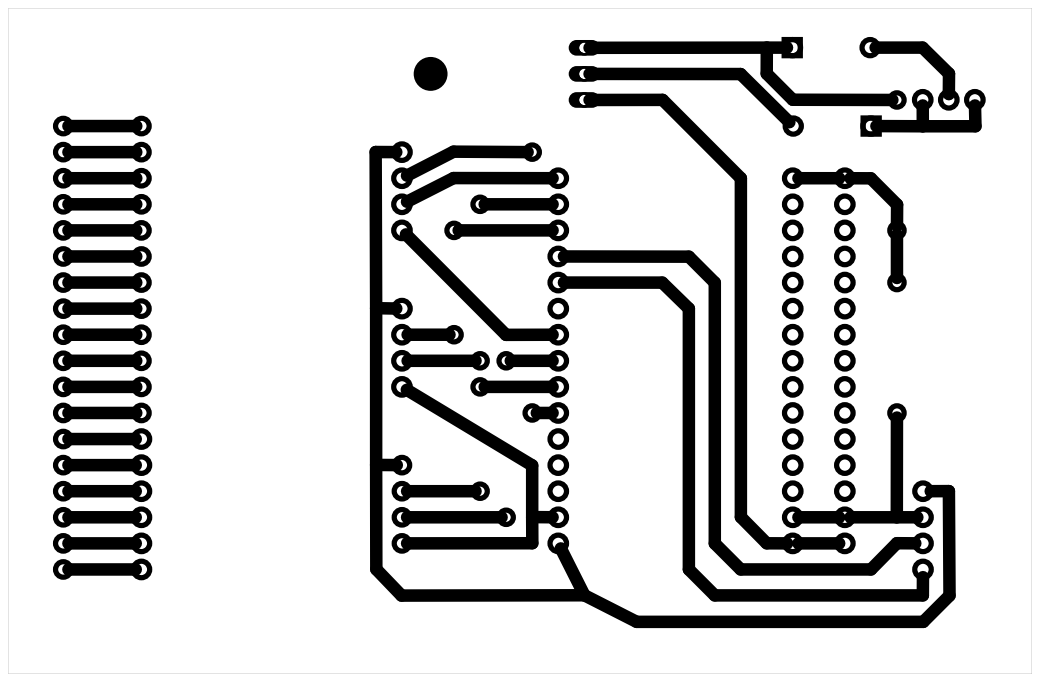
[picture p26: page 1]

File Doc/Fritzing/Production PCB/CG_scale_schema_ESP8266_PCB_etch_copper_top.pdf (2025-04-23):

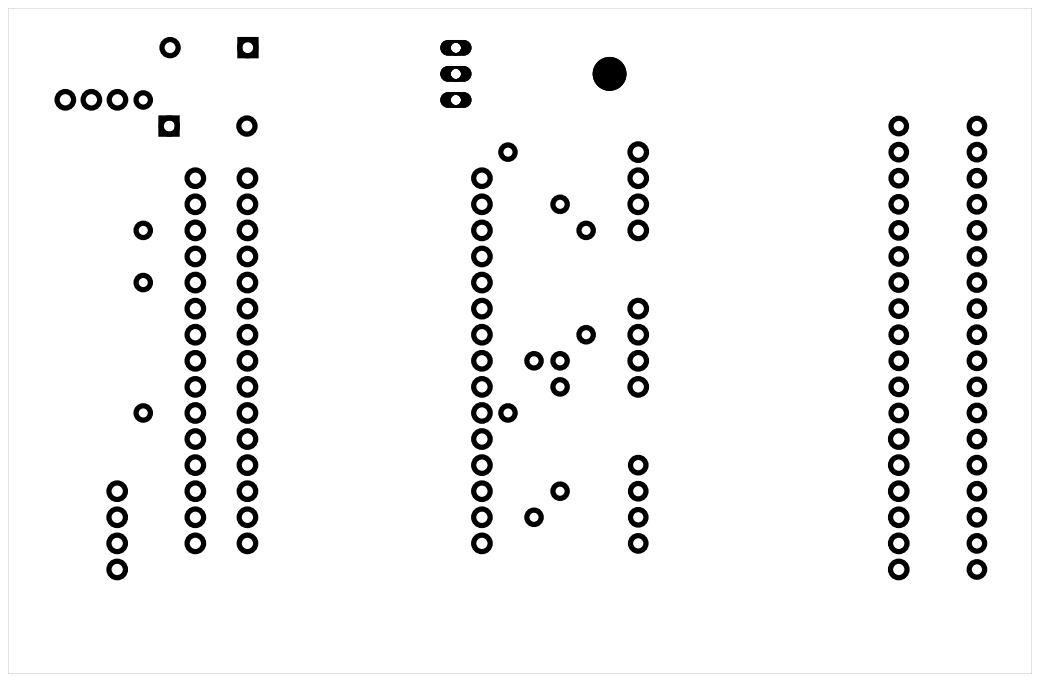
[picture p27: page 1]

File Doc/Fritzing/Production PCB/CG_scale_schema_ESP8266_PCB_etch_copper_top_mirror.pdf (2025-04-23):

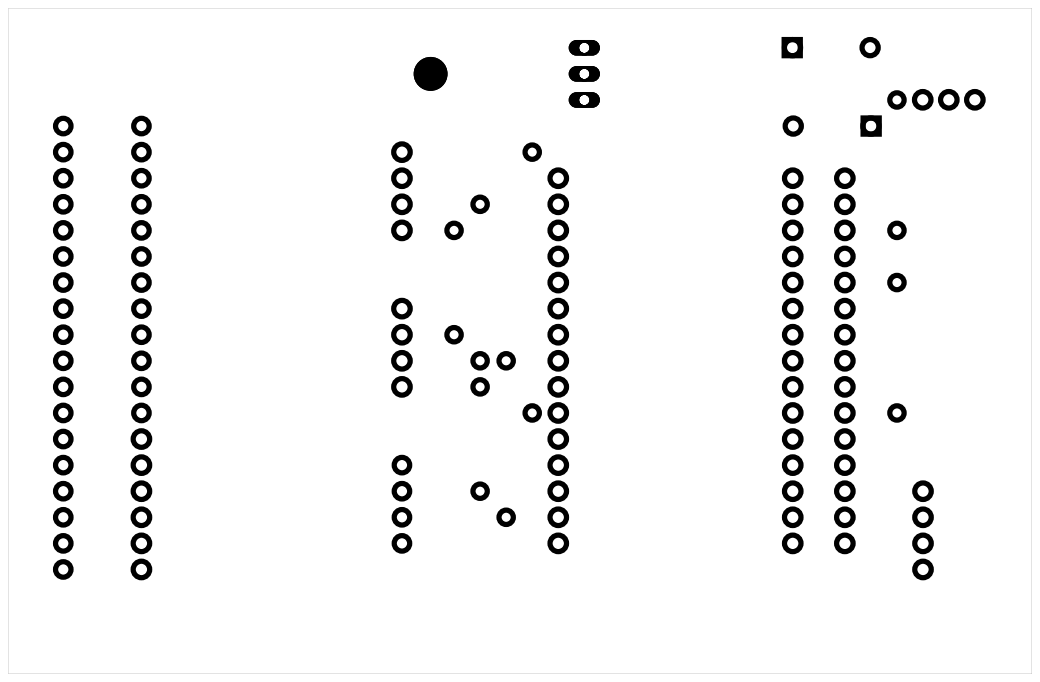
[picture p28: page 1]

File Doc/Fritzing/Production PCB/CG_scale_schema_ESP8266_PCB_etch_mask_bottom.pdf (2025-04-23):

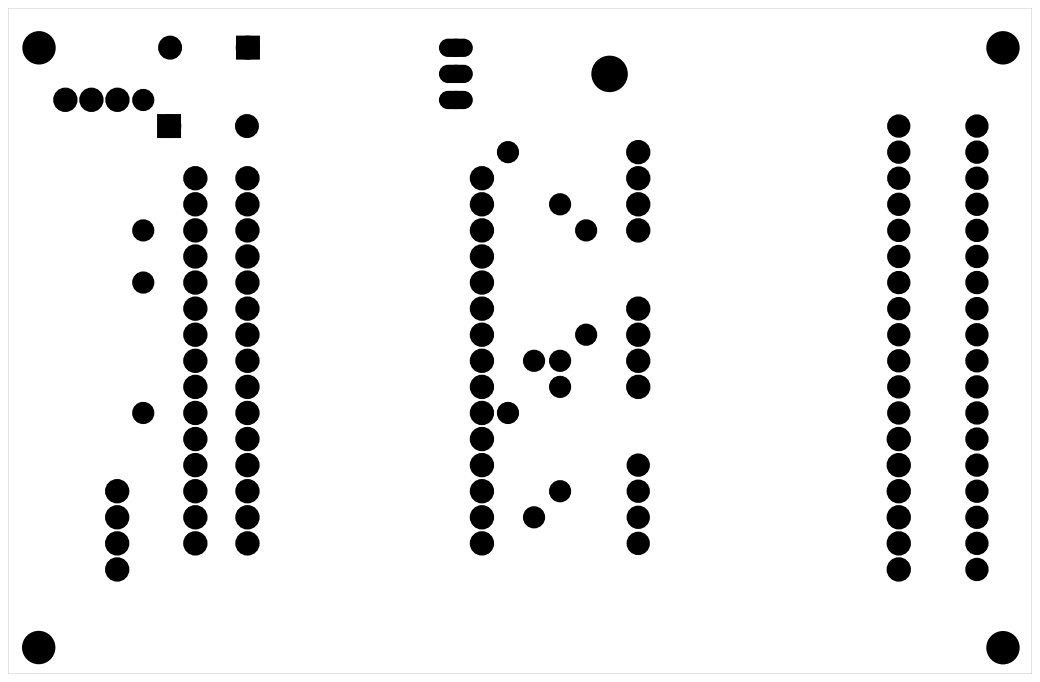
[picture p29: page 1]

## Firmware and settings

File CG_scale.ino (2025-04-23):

/*
  ------------------------------------------------------------------
                            CG scale
                      (c) 2019-2025 by M. Lehmann
  ------------------------------------------------------------------
*/
#define CGSCALE_VERSION "2.31"
/*

  ******************************************************************
  history:
  V2.31   22.04.25     Library update to littleFS, ArduinoJson 7, webpage update, add color profiles
  V2.3    01.03.22     Up to three ESPs can be linked via WLAN. Useful for landing gear scales on engine models
  V2.22   28.11.20     fixed RAM problems with JSON
  V2.21   27.11.20     bug fixed: recompiled, binary file incorrect
  V2.2    01.11.20     Virtual weights built in
  V2.12   07.10.20     bug fixed: LR value was displayed in the wrong display position
                       Voltage for specified battery types deleted
  V2.11   18.08.20     code is now compatible with standard OLED displays
                       and original code base (default pw length = 32)
  V2.1    18.07.20     added support for ESP8266 based Wifi Kit 8
  (by Pulsar07/           (https://heltec.org/project/wifi-kit-8/)
   R.Stransky             is a ESP8266 with
                            a build in OLED 128x32
                            battery connector with charging management
                            reset and GPIO0 button
                        support for a tare button (PIN_TARE_BUTTON)
                        bug fixed: wifi password now with up to 64 chars
                        bug fixed: wifi data (ssid/passwd) with special
                          character (e.g. +) is now supported
                        for specified battery type, voltage is displayed
                        using uncompressed html files makes WEB GUI much faster
  V2.01   29.01.20      small bug fixes with AVR
  V2.0    26.01.20      Webpage rewritten, no bootstrap framework needed
                        add translation to webpage (en, de)
                        optimized for measuring with landinggears
                        updated to ArduinoJson V6
                        firmware update over web interface
  V1.2.1  31.03.19      small bug fixed
                        values in model database are rounded
                        mDNS and OTA did not work in AP mode
  V1.2    23.02.19      Add OTA (over the air update)
                        mDNS default enabled
                        add percentlists for many battery types
                        memory optimization
  V1.1    02.02.19      Supports ESP8266, webpage integrated, STA and AP mode
  V1.0    12.01.19      first release


  ******************************************************************

  Software License Agreement (BSD License)

  Copyright (c) 2019-2024, Michael Lehmann
  All rights reserved.

  Redistribution and use in source and binary forms, with or without
  modification, are permitted provided that the following conditions are met:
  1. Redistributions of source code must retain the above copyright
  notice, this list of conditions and the following disclaimer.
  2. Redistributions in binary form must reproduce the above copyright
  notice, this list of conditions and the following disclaimer in the
  documentation and/or other materials provided with the distribution.
  3. Neither the name of the copyright holders nor the
  names of its contributors may be used to endorse or promote products
  derived from this software without specific prior written permission.

  THIS SOFTWARE IS PROVIDED BY THE COPYRIGHT HOLDERS ''AS IS'' AND ANY
  EXPRESS OR IMPLIED WARRANTIES, INCLUDING, BUT NOT LIMITED TO, THE IMPLIED
  WARRANTIES OF MERCHANTABILITY AND FITNESS FOR A PARTICULAR PURPOSE ARE
  DISCLAIMED. IN NO EVENT SHALL THE COPYRIGHT HOLDER BE LIABLE FOR ANY
  DIRECT, INDIRECT, INCIDENTAL, SPECIAL, EXEMPLARY, OR CONSEQUENTIAL DAMAGES
  (INCLUDING, BUT NOT LIMITED TO, PROCUREMENT OF SUBSTITUTE GOODS OR SERVICES;
  LOSS OF USE, DATA, OR PROFITS; OR BUSINESS INTERRUPTION) HOWEVER CAUSED AND
  ON ANY THEORY OF LIABILITY, WHETHER IN CONTRACT, STRICT LIABILITY, OR TORT
  (INCLUDING NEGLIGENCE OR OTHERWISE) ARISING IN ANY WAY OUT OF THE USE OF THIS
  SOFTWARE, EVEN IF ADVISED OF THE POSSIBILITY OF SUCH DAMAGE.

*/

// **** Please UNCOMMENT to choose special hardware *****************

//#define WIFI_KIT_8    //is a ESP8266 based board, with integrated OLED and battery management



// ******************************************************************
// Arduino IDE V2.3.6

// Required libraries, can be installed from the library manager
#include <HX711_ADC.h>      // library for the HX711 24-bit ADC for weight scales (https://github.com/olkal/HX711_ADC)
#include <U8g2lib.h>        // Universal 8bit Graphics Library (https://github.com/olikraus/u8g2/)

// built-in libraries
#include <EEPROM.h>
#include <Wire.h>

// libraries for ESP8266
#if defined(ESP8266)
#include <FS.h>
#include <LittleFS.h>
#include <ESP8266WiFi.h>
#include <ESP8266WebServer.h>
#include <WiFiClientSecure.h>
#include <ESP8266HTTPClient.h>
#include <ESP8266mDNS.h>
#include <WiFiUdp.h>
#include <ArduinoOTA.h>
#include <ElegantOTA.h> //V2.2.9
#include <ArduinoJson.h> //V7.4.1
#endif

// load settings
#if defined(__AVR__)
  #include "settings_AVR.h"
#elif defined(ESP8266)
  #ifdef WIFI_KIT_8
    #include "settings_WIFI_KIT_8.h"
  #else
    #include "settings_ESP8266.h"
  #endif
#endif

// HX711 constructor array (dout pin, sck pint):
HX711_ADC LoadCell[] {HX711_ADC(PIN_LOADCELL1_DOUT, PIN_LOADCELL1_PD_SCK), HX711_ADC(PIN_LOADCELL2_DOUT, PIN_LOADCELL2_PD_SCK), HX711_ADC(PIN_LOADCELL3_DOUT, PIN_LOADCELL3_PD_SCK)};

// webserver constructor
#if defined(ESP8266)
ESP8266WebServer server(80);
IPAddress apIP(ip[0], ip[1], ip[2], ip[3]);
WiFiClientSecure httpsClient;
File fsUploadFile;              // a File object to temporarily store the received file
#endif

#include "defaults.h"

struct VirtualWeight {
  String name;
  float cg;
  float weight;
  bool enabled = false;
};

struct Model {
  float distance[3] = {DISTANCE_X1, DISTANCE_X2, DISTANCE_X3};
#if defined(ESP8266)
  char name[MAX_MODELNAME_LENGHT + 1] = "";
  float targetCGmin = 0;
  float targetCGmax = 0;
  uint8_t mechanicsType = 0;
  VirtualWeight virtualWeight[MAX_VIRTUAL_WEIGHT];
#endif
};

Model model;

// load default values
uint8_t nLoadcells = NUMBER_LOADCELLS;
float calFactorLoadcell[] = {LOADCELL1_CALIBRATION_FACTOR, LOADCELL2_CALIBRATION_FACTOR, LOADCELL3_CALIBRATION_FACTOR};
float resistor[] = {RESISTOR_R1, RESISTOR_R2};
uint8_t batType = BAT_TYPE;
uint8_t batCells = BAT_CELLS;
float refWeight = REF_WEIGHT;
float refCG = REF_CG;
#if defined(ESP8266)
char device_Name[MAX_SSID_PW_LENGHT + 1] = SSID_AP;
char ssid_STA[MAX_SSID_PW_LENGHT + 1] = SSID_STA;
char password_STA[MAX_SSID_PW_LENGHT + 1] = PASSWORD_STA;
char ssid_AP[MAX_SSID_PW_LENGHT + 1] = SSID_AP;
char password_AP[MAX_SSID_PW_LENGHT + 1] = PASSWORD_AP;
char loadCellURL[3][MAX_SSID_PW_LENGHT + 1] = {"","",""};
bool enableUpdate = ENABLE_UPDATE;
bool enableOTA = ENABLE_OTA;
#endif

// declare variables
float weightLoadCell[] = {0, 0, 0};
float lastWeightLoadCell[] = {0, 0, 0};
float weightTotal = 0;
float CG_length = 0;
float CG_trans = 0;
float batVolt = 0;
unsigned long lastTimeMenu = 0;
unsigned long lastTimeLoadcell = 0;
bool updateMenu = true;
int menuPage = 0;
String errMsg[5];
int errMsgCnt = 0;
const uint8_t *oledFontBig;
const uint8_t *oledFontLarge;
const uint8_t *oledFontNormal;
const uint8_t *oledFontSmall;
#if defined(ESP8266)
String updateMsg = "";
bool wifiSTAmode = true;
float gitVersion = -1;
unsigned long ota_progress_millis = 0;
#endif



// Restart CPU
#if defined(__AVR__)
void(* resetCPU) (void) = 0;
#elif defined(ESP8266)
void resetCPU() {}
#endif


// convert time to string
char * TimeToString(unsigned long t)
{
  static char str[13];
  int h = t / 3600000;
  t = t % 3600000;
  int m = t / 60000;
  t = t % 60000;
  int s = t / 1000;
  int ms = t - (s * 1000);
  sprintf(str, "%02ld:%02d:%02d.%03d", h, m, s, ms);
  return str;
}


// Count percentage from cell voltage
int percentBat(float cellVoltage) {

  int result = 0;
  int elementCount = DATAPOINTS_PERCENTLIST;
  byte batTypeArray = batType - 2;

  for (int i = 0; i < elementCount; i++) {
    if (pgm_read_float( &percentList[batTypeArray][i][1]) == 100 ) {
      elementCount = i;
      break;
    }
  }

  float cellempty = pgm_read_float( &percentList[batTypeArray][0][0]);
  float cellfull = pgm_read_float( &percentList[batTypeArray][elementCount][0]);

  if (cellVoltage >= cellfull) {
    result = 100;
  } else if (cellVoltage <= cellempty) {
    result = 0;
  } else {
    for (int i = 0; i <= elementCount; i++) {
      float curVolt = pgm_read_float(&percentList[batTypeArray][i][0]);
      if (curVolt >= cellVoltage && i > 0) {
        float lastVolt = pgm_read_float(&percentList[batTypeArray][i - 1][0]);
        float curPercent = pgm_read_float(&percentList[batTypeArray][i][1]);
        float lastPercent = pgm_read_float(&percentList[batTypeArray][i - 1][1]);
        result = float((cellVoltage - lastVolt) / (curVolt - lastVolt)) * (curPercent - lastPercent) + lastPercent;
        break;
      }
    }
  }

  return result;
}


void printConsole(int t, String msg) {
  Serial.print(TimeToString(millis()));
  Serial.print(" [");
  switch (t) {
    case T_BOOT:
      Serial.print("BOOT");
      break;
    case T_RUN:
      Serial.print("RUN");
      break;
    case T_ERROR:
      Serial.print("ERROR");
      break;
    case T_WIFI:
      Serial.print("WIFI");
      break;
    case T_UPDATE:
      Serial.print("UPDATE");
      break;
    case T_HTTPS:
      Serial.print("HTTPS");
      break;
  }
  Serial.print("] ");
  Serial.println(msg);
}


void initOLED() {
  oledDisplay.begin();
  printConsole(T_BOOT, "init OLED display: " + String(DISPLAY_WIDTH) + String("x") + String(DISPLAY_HIGHT));

#if DISPLAY_HIGHT > 32
  oledFontBig    = u8g2_font_helvR18_tn;
  oledFontLarge  = u8g2_font_helvR12_tr;
  oledFontNormal = u8g2_font_helvR10_tr;
  oledFontSmall  = u8g2_font_5x7_tr;
#elif DISPLAY_HIGHT <= 32
  oledFontBig    = u8g2_font_helvR14_tr;
  oledFontLarge  = u8g2_font_helvR10_tr;
  oledFontNormal = u8g2_font_6x12_tr;
  oledFontSmall  = u8g2_font_5x7_tr;
#endif

  int ylineHeight = DISPLAY_HIGHT / 3;

  oledDisplay.firstPage();
  do {
    oledDisplay.setFont(oledFontLarge);
#if DISPLAY_HIGHT <= 32
    oledDisplay.drawXBMP(5, 0, 18, 18, CGImage);
#else
    oledDisplay.drawXBMP(20, 12, 18, 18, CGImage);
#endif
    oledDisplay.setFont(oledFontLarge);

#if DISPLAY_HIGHT <= 32
    oledDisplay.setCursor(30, 12);
#else
    oledDisplay.setCursor(45, 28);
#endif
    oledDisplay.print(F("CG scale"));

    oledDisplay.setFont(oledFontSmall);
#if DISPLAY_HIGHT <= 32
    oledDisplay.setCursor(30, 22);
#else
    oledDisplay.setCursor(35, 55);
#endif
    oledDisplay.print(F("Version: "));
    oledDisplay.print(CGSCALE_VERSION);
#if DISPLAY_HIGHT <= 32
    oledDisplay.setCursor(5, 31);
#else
    oledDisplay.setCursor(20, 64);
#endif
    oledDisplay.print(F("(c) 2025 M.Lehmann"));

  } while ( oledDisplay.nextPage() );
}


void printOLED(String aLine1, String aLine2, String aLine3) {
  int ylineHeight = DISPLAY_HIGHT / 3;

  oledDisplay.firstPage();
  do {
    oledDisplay.setFont(oledFontNormal);
    oledDisplay.setCursor(0, ylineHeight * 1);
    oledDisplay.print(aLine1);
    oledDisplay.setCursor(0, ylineHeight * 2);
    oledDisplay.print(aLine2);
    oledDisplay.setCursor(0, DISPLAY_HIGHT);
    oledDisplay.print(aLine3);
  } while ( oledDisplay.nextPage() );
}

void printScaleOLED() {
  // print to display
  char buff[8];
  int pos_weightTotal = 7;
  int pos_CG_length = 28;
  if (nLoadcells == 2) {
    pos_weightTotal = 17;
    pos_CG_length = 45;
    if (batType == 0) {
      pos_weightTotal = 12;
      pos_CG_length = 40;
    }
  }

  oledDisplay.firstPage();
  do {
    if (errMsgCnt == 0) {
      // print battery
      if (batType > B_OFF) {
        oledDisplay.drawXBMP(88, 1, 12, 6, batteryImage);
        if (batType == B_VOLT) {
          dtostrf(batVolt, 2, 2, buff);
        } else {
          dtostrf(batVolt, 3, 0, buff);
          oledDisplay.drawBox(89, 2, (batVolt / (100 / 8)), 4);
        }
        oledDisplay.setFont(oledFontSmall);
        oledDisplay.setCursor(123 - oledDisplay.getStrWidth(buff), 7);
        oledDisplay.print(buff);
        if (batType == B_VOLT) {
          oledDisplay.print(F("V"));
        } else {
          oledDisplay.print(F("%"));
        }
      }
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
void loop() {

#if defined(ESP8266)

#if ENABLE_MDNS
  MDNS.update();
#endif

  if (enableOTA) {
    //ArduinoOTA.handle();
  }
  server.handleClient();
#endif

#ifdef PIN_TARE_BUTTON
  handleTareBtn();
#endif

  updateLoadcells();

  // update loadcell values
  if ((millis() - lastTimeLoadcell) > UPDATE_INTERVAL_LOADCELL) {
    lastTimeLoadcell = millis();

    errMsgCnt = 0;
    getLoadcellError();

    // read battery voltage
    if (batType > B_OFF) {
      batVolt = (analogRead(VOLTAGE_PIN) / 1024.0) * V_REF * ((resistor[R1] + resistor[R2]) / resistor[R2]) / 1000.0;
#if ENABLE_PERCENTLIST
      if (batType > B_VOLT) {
        batVolt = percentBat(batVolt / batCells);
      }
#endif
    }

    // get Loadcell weights
    for (int i = LC1; i <= LC3; i++) {
      if (i < nLoadcells) {
#if defined(ESP8266)
        if(strlen(loadCellURL[i]) == 0){
#endif
          // get local data
          weightLoadCell[i] = LoadCell[i].getData();

          // IIR filter
          weightLoadCell[i] = weightLoadCell[i] + SMOOTHING_LOADCELL * (lastWeightLoadCell[i] - weightLoadCell[i]);
          lastWeightLoadCell[i] = weightLoadCell[i];
#if defined(ESP8266)
        }else{
          // get data from external server
          WiFiClient client;
          HTTPClient http;
          
          http.begin(client, "http://" + String(loadCellURL[i]) + "/getRawValue");
          http.setTimeout(2000);
          int httpCode = http.GET();

          if (httpCode == HTTP_CODE_OK) {
            const String& txt = http.getString();

            // split response string
            int delimiterStartIndex = 0;
            int delimiterEndIndex = 0;
            String subString[10];
            int subStringCount = 0;
            while(delimiterEndIndex > -1){
              delimiterEndIndex = txt.indexOf('&',delimiterStartIndex);
              subString[subStringCount] = txt.substring(delimiterStartIndex,delimiterEndIndex);
              ++subStringCount;
              delimiterStartIndex = delimiterEndIndex+1;
            }

            weightLoadCell[i] = subString[LC1].toFloat();

            float extBatVolt = subString[3].toFloat();
            if (batType > B_VOLT && batVolt > extBatVolt) {
              batVolt = extBatVolt;
            }
          } else {
            String msg = "ERROR: Lc" + String(i + 1) + " no data";
            errMsg[++errMsgCnt] = msg + "\n";
            printConsole(T_ERROR, msg);
          }
          
          http.end();
        }
#endif
      }
    }
  }


  // update display and serial menu
  if ((millis() - lastTimeMenu) > UPDATE_INTERVAL_OLED_MENU) {

    lastTimeMenu = millis();

    // total model weight
    weightTotal = weightLoadCell[LC1] + weightLoadCell[LC2] + weightLoadCell[LC3];
    if (weightTotal < MINIMAL_TOTAL_WEIGHT && weightTotal > MINIMAL_TOTAL_WEIGHT * -1) {
      weightTotal = 0;
    }

    if (weightTotal > MINIMAL_CG_WEIGHT) {
      if (nLoadcells > 1) {
        // CG longitudinal axis
        CG_length = ((weightLoadCell[LC2] * model.distance[X2]) / weightTotal) + model.distance[X1];
  
#if defined(ESP8266)
        if (model.mechanicsType == 2) {
          CG_length = ((weightLoadCell[LC2] * model.distance[X2]) / weightTotal) - model.distance[X1];
        } else if (model.mechanicsType == 3) {
          CG_length = ((weightLoadCell[LC2] * model.distance[X2]) / weightTotal) * -1 + model.distance[X1];
        }
  
        /* Virtual weights 
  
        m = weight
        d = cg
        d_new=(m1*d1+m2*d2)/(m1+m2)
        */
  
        for (int i=0; i < MAX_VIRTUAL_WEIGHT; i++){
          if(model.virtualWeight[i].enabled == true){
            CG_length = (weightTotal * CG_length + model.virtualWeight[i].weight * model.virtualWeight[i].cg) / (weightTotal + model.virtualWeight[i].weight);
          }
        }
  
        for (int i=0; i < MAX_VIRTUAL_WEIGHT; i++){
          if(model.virtualWeight[i].enabled == true){
            weightTotal +=  model.virtualWeight[i].weight;
          }
        }
        
  #endif
  
        // CG transverse axis
        if (nLoadcells == 3) {
          CG_trans = (model.distance[X3] / 2) - (((weightLoadCell[LC1] + weightLoadCell[LC2] / 2) * model.distance[X3]) / weightTotal);
        }
      }

    } else {
      CG_length = 0;
      CG_trans = 0;
    }

    

    printScaleOLED();  

    // serial connection
    if (Serial) {
      if (Serial.available() > 0) {

        switch (menuPage)
        {
          case MENU_HOME:
            menuPage = Serial.parseInt();
            updateMenu = true;
            break;
          case MENU_LOADCELLS:
            nLoadcells = Serial.parseInt();
            EEPROM.put(P_NUMBER_LOADCELLS, nLoadcells);
#if defined(ESP8266)
            EEPROM.commit();
#endif
            menuPage = 0;
            updateMenu = true;
            break;
          case MENU_DISTANCE_X1 ... MENU_DISTANCE_X3:
            model.distance[menuPage - MENU_DISTANCE_X1] = Serial.parseFloat();
            EEPROM.put(P_DISTANCE_X1 + ((menuPage - MENU_DISTANCE_X1) * sizeof(float)), model.distance[menuPage - MENU_DISTANCE_X1]);
#if defined(ESP8266)
            EEPROM.commit();
#endif
            menuPage = 0;
            updateMenu = true;
            break;
          case MENU_REF_WEIGHT:
            refWeight = Serial.parseFloat();
            EEPROM.put(P_REF_WEIGHT, refWeight);
#if defined(ESP8266)
            EEPROM.commit();
#endif
            menuPage = 0;
            updateMenu = true;
            break;
          case MENU_REF_CG:
            refCG = Serial.parseFloat();
            EEPROM.put(P_REF_CG, refCG);
#if defined(ESP8266)
            EEPROM.commit();
#endif
            menuPage = 0;
            updateMenu = true;
            break;
          case MENU_AUTO_CALIBRATE:
            if (Serial.read() == 'Y') {
              runAutoCalibrate();
            }
            menuPage = 0;
            updateMenu = true;
            break;
          case MENU_LOADCELL1_CALIBRATION_FACTOR ... MENU_LOADCELL3_CALIBRATION_FACTOR:
            calFactorLoadcell[menuPage - MENU_LOADCELL1_CALIBRATION_FACTOR] = Serial.parseFloat();
            saveCalFactor(menuPage - MENU_LOADCELL1_CALIBRATION_FACTOR);
            menuPage = 0;
            updateMenu = true;
            break;
          case MENU_RESISTOR_R1 ... MENU_RESISTOR_R2:
            resistor[menuPage - MENU_RESISTOR_R1] = Serial.parseFloat();
            EEPROM.put(P_RESISTOR_R1 + ((menuPage - MENU_RESISTOR_R1) * sizeof(float)), resistor[menuPage - MENU_RESISTOR_R1]);
#if defined(ESP8266)
            EEPROM.commit();
#endif
            menuPage = 0;
            updateMenu = true;
            break;
          case MENU_BATTERY_MEASUREMENT:
            batType = Serial.parseInt();
            EEPROM.put(P_BAT_TYPE, batType);
#if defined(ESP8266)
            EEPROM.commit();
#endif
            menuPage = 0;
            updateMenu = true;
            break;
          case MENU_BATTERY_CELLS:
            batCells = Serial.parseInt();
            EEPROM.put(P_BATT_CELLS, batCells);
#if defined(ESP8266)
            EEPROM.commit();
#endif
            menuPage = 0;
            updateMenu = true;
            break;
          case MENU_RESET_DEFAULT:
            if (Serial.read() == 'Y') {
              resetFactoryDefaults();
            }
            menuPage = 0;
            updateMenu = true;
            break;
          default:
            Serial.readString();
            menuPage = 0;
            updateMenu = true;
            break;
        }
        Serial.readString();

      }

      if (!updateMenu)
        return;

      switch (menuPage)
      {
        case MENU_HOME: {
            Serial.print(F("\n\n********************************************\nCG scale by M.Lehmann - V"));
            Serial.print(CGSCALE_VERSION);
            Serial.print(F("\n\n"));

            Serial.print(MENU_LOADCELLS);
            Serial.print(F("  - Set number of load cells ("));
            Serial.print(nLoadcells);
            Serial.print(F(")\n"));

            for (int i = X1; i <= X3; i++) {
              Serial.print(MENU_DISTANCE_X1 + i);
              Serial.print(F("  - Set distance X"));
              Serial.print(i + 1);
              Serial.print(F(" ("));
              Serial.print(model.distance[i]);
              Serial.print(F("mm)\n"));
            }

            Serial.print(MENU_REF_WEIGHT);
            Serial.print(F("  - Set reference weight ("));
            Serial.print(refWeight);
            Serial.print(F("g)\n"));

            Serial.print(MENU_REF_CG);
            Serial.print(F("  - Set reference CG ("));
            Serial.print(refCG);
            Serial.print(F("mm)\n"));

            Serial.print(MENU_AUTO_CALIBRATE);
            Serial.print(F("  - Start autocalibration\n"));
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

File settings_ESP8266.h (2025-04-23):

/*
  -----------------------------------------------------------
            Settings for ESP8266 based MCUs
  -----------------------------------------------------------
  General settings for the CG scale.
*/

// **** Loadcell hardware settings ****

#define NUMBER_LOADCELLS                3       // if set to 2, the parameters of loadcell 3 are ignored

#define DISTANCE_X1                     30      // mm
#define DISTANCE_X2                     350     // mm
#define DISTANCE_X3                     220     // mm

#define LOADCELL1_CALIBRATION_FACTOR    900     // user set calibration factor
#define LOADCELL2_CALIBRATION_FACTOR    900     // user set calibration factor
#define LOADCELL3_CALIBRATION_FACTOR    900     // user set calibration factor

/*
CG scale with 2 Loadcells:


<-         ||=== Loadcell 1 ========== Loadcell 2
                
            |        |                     |
            |---X1---|---------X2----------|



CG scale with 3 Loadcells:

       --   ||   Loadcell 1
       |    ||      ||
       |    ||      ||
       |    ||      ||
<-    X3    ||      ||================ Loadcell 2
       |    ||      ||
       |    ||      ||
       |    ||      ||
       --   ||   Loadcell 3 
                
            |        |                     |
            |---X1---|---------X2----------|
*/


#define PIN_LOADCELL1_DOUT            D6
#define PIN_LOADCELL1_PD_SCK          D5

#define PIN_LOADCELL2_DOUT            D2
#define PIN_LOADCELL2_PD_SCK          D1

#define PIN_LOADCELL3_DOUT            D7
#define PIN_LOADCELL3_PD_SCK          D0



// **** Measurement settings ****

#define STABILISINGTIME               3000     // ms

#define UPDATE_INTERVAL_OLED_MENU     500      // ms
#define UPDATE_INTERVAL_LOADCELL      100      // ms

#define SMOOTHING_LOADCELL            0.4     // IIR filter: smoothing value from 0.00-1.00

#define MINIMAL_CG_WEIGHT             10      // g     if lower, no CG is displayed (0mm)
#define MINIMAL_TOTAL_WEIGHT          1       // g     if lower, weight = 0 is displayed



// **** Calibration settings ****

#define REF_WEIGHT                    1500     // g
#define REF_CG                        100      // mm



// **** Display settings ****

// Please UNCOMMENT the display used

U8G2_SH1106_128X64_NONAME_1_HW_I2C oledDisplay(U8G2_R0, /* reset=*/ U8X8_PIN_NONE, /* clock=*/ D3, /* data=*/ D4);
//U8G2_SSD1306_128X64_NONAME_1_HW_I2C oledDisplay(U8G2_R0, /* reset=*/ U8X8_PIN_NONE, /* clock=*/ D3, /* data=*/ D4);

#define DISPLAY_WIDTH                 128
#define DISPLAY_HIGHT                 64


// **** Voltage measurement settings ****

// analog input pin
#define VOLTAGE_PIN                   A0

// supply voltage
#define V_REF                         3300     // set supply voltage from 1800 to 5500mV

// voltage divider
#define RESISTOR_R1                   20000    // ohm
#define RESISTOR_R2                   10000    // ohm

/*
                  voltage input
                     |
                     |
                    | |
                    | |  R1
                    | |
                     |
  analog Pin  <------+
                     |
                    | |
                    | |  R2
                    | |
                     |
                     |
                    GND
*/

// calculate voltage to percent
#define ENABLE_PERCENTLIST            true

// Battery type
#define BAT_TYPE                      B_VOLT

// Battery cells
#define BAT_CELLS                     2



// **** Wifi settings ****

#define MAX_SSID_PW_LENGHT          32

// Station mode: connect to available network
#define SSID_STA                    "myWiFi"
#define PASSWORD_STA                ""
#define TIMEOUT_CONNECT             25000   //ms

// Access point mode: create own network
#define SSID_AP                     "CG scale"
#define PASSWORD_AP                 ""
const char ip[4] =                  {1,2,3,4};    // default IP address

#define ENABLE_MDNS                 true          // enable mDNS to reach the webpage with hostname.local
#define ENABLE_OTA                  true          // enable over the air update



// **** https update settings ****

#define ENABLE_UPDATE               true
#define HTTPS_PORT                  443
#define HOST                        "github.com"
#define URL                         "/nightflyer88/CG_scale/releases/latest"



// **** Model memory settings ****

#define MAX_MODELNAME_LENGHT        32               // max chars 
#define DEFAULT_NAME                "Model"          // default model name
#define MODEL_FILE                  "/models.json"   // file to store models


// **** Color profile settings ****
#define COLOR_FILE                  "/color.json"   // file to store color profile



// **** virtual weight settings ****

#define MAX_VIRTUAL_WEIGHT              10               



// **** end of settings ****
#warning ESP8266 settings have been loaded

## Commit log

2019-01-17 add error messages, timeout tare
    [CG_scale.ino, settings_AVR.h, settings_ESP8266.h]
2019-01-27 add mDNS service, add tare button, tare procedure improved
2019-02-10 add OTA updates, enable mDNS
    [CG_scale_schema.fzz, CG_scale_schema_ESP8266.fzz]
2020-07-18 V2.1 18.07.20 added support for ESP8266 based Wifi Kit 8 (by Pulsar07/ (https://heltec.org/project/wifi-kit-8/) R.Stransky is a ESP8266 with * a build in OLED 128x32 * battery connector with charging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
    [CG_scale.ino, settings_ESP8266.h]
2020-09-27 update html files
    add tare button in settings menu
2020-11-28 fixed RAM problems with JSON
    [CG_scale.ino]
2024-11-15 Move rename img in img_DE
    [CG_scale_schema_ESP8266_Mini.fzz]
2024-11-15 Add OLED fritzzing
    [CG_scale_schema_ESP8266_OLED_display.fzz]
2024-11-15 PCB
    Add PCB Board
    [CG_scale_schema_ESP8266_PCB.fzz]
2024-11-15 PCB Optimized
    [CG_scale_schema_ESP8266_PCB.fzz, CG_scale_schema_ESP8266_PCB_Optimise.fzz]
2024-11-15 Add Oled Box
    [Box_Oled.FCStd, Box_Oled_Bottom.stl, Box_Oled_Top.stl]
2024-11-15 Add image
    [Balance 5mm.FCStd, CG_scale_schema.fzz, CG_scale_schema_ESP8266.fzz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]
2024-11-16 Update Fritzzing
    [CG_scale_schema_ESP8266_OLED_display.fzz, CG_scale_schema_ESP8266_PCB_Optimise.fzz]
2025-04-22 V2.31
    Library update to littleFS, ArduinoJson 7, webpage update, add color profiles
2025-10-13 added support for ESP32
